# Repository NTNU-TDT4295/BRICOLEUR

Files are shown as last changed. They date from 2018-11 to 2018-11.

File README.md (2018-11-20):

# BRICOLEUR

This is the collision detection group's final submission for the course TDT4295 Computer Design Project 2018. This course aims to give students an introduction to the process of designing physical computer solutions, from start to finish. The project was completed on a budget of 10000 NOK, of which 5400 NOK were spent. 

## What is BRICOLEUR?
A bricoleur is someone who starts building something with no clear plan, adding bits here and there, cobbling together a whole while flying by the seat of their pants.

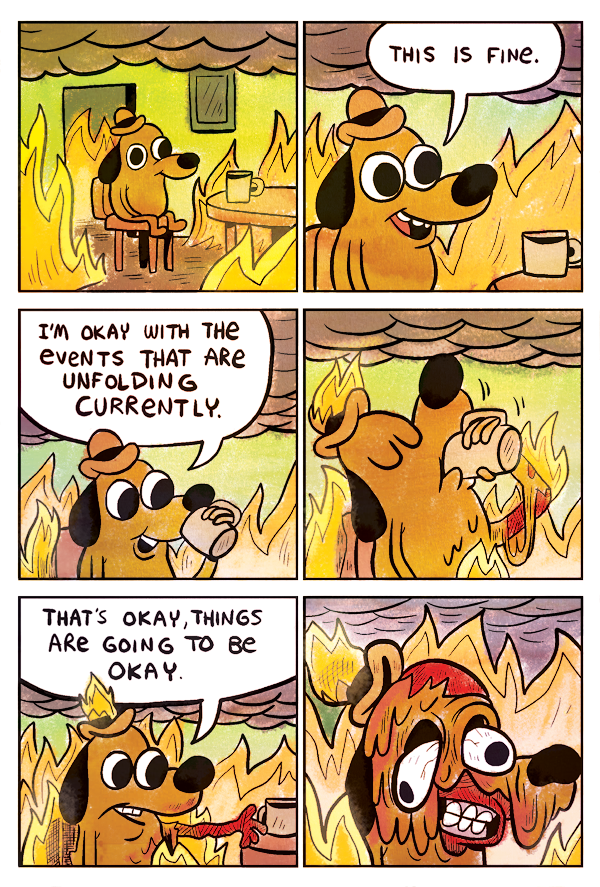
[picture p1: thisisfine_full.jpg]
We have everything under control Everything is fine


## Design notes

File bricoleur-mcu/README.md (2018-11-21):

# Ultrasonic

Reads ultrasonic sensors and processes the readings.
Uses the EFM32GG MCU and LV-MaxSonar-EZ0 rangefinders.

## Setup

Current setup uses an EFM32GG980 and two EZ0 rangefinders.

### Wiring (ultrasonic)

The EZ0 sends range data in inverted UART format.

| MCU | EZ0 |
|-----|---|
| 3V3 |  +5 |
| GND | GND |
| PA0 | TX\* |
| PA3 | RX\*\* |
| PA4 | RX\*\* |

\* The outputs from the sensors must be connected together with a "binary or".
This means that the signal from each sensor must go trough a diode before the signals are connected together and to the MCU. The signal must also have a pull-down resistor.

\*\* The RX pin on each sensor must be connected to its own pin on the MCU.

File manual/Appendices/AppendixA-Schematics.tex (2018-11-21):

\section{Appendix A: Schematics}
%TODO: Remove blank page
\label{AppendixA}
%\includepdf[pages=1,pagecommand={\subsection{Appendix A: Schematics} \thispagestyle{empty}}, fitpaper=true]{Images/Schematics-PleaseDoUseInReport.pdf} [width=155mm,height=220mm]
\includepdf[pages=1,fitpaper, width=216mm, height=297mm ]{Images/Schematics-PleaseDoUseInReport.pdf}
\includepdf[pages=2,fitpaper, width=216mm, height=297mm]{Images/Schematics-PleaseDoUseInReport.pdf}
\includepdf[pages=3,fitpaper, width=216mm, height=297mm]{Images/Schematics-PleaseDoUseInReport.pdf}
\includepdf[pages=4,fitpaper, width=216mm, height=297mm]{Images/Schematics-PleaseDoUseInReport.pdf}
\includepdf[pages=5,fitpaper, width=216mm, height=297mm]{Images/Schematics-PleaseDoUseInReport.pdf}

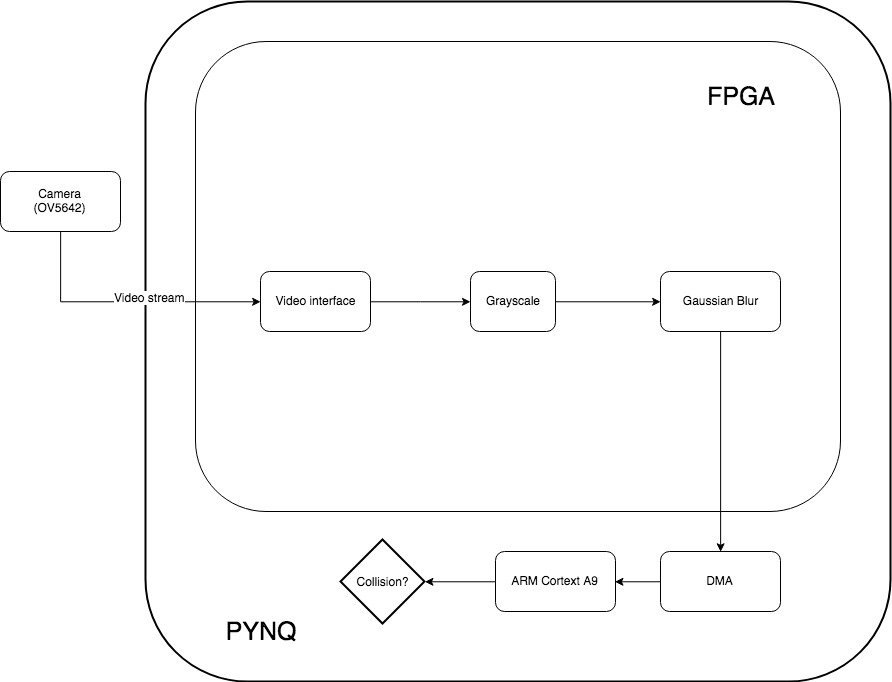
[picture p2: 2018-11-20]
manual/Images/Pipeline-Overview.jpg

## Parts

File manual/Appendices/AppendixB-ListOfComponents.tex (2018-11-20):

\section{Appendix B - Components}
The following is a list of all components used in the assembly of one copy of the BRICOLEUR system. 
\subsection{Pre-made components}
\begin{tabular}{c | r}
    Component & Quantity            \\ \hline
    CMOS OV5642 Camera Module  & 1  \\
    LV-MaxSonar-EZ0 MB1000 & 2      \\
    PYNQ-Z1 & 1                     \\
    Cardboard container & 1          \\
\end{tabular}

\subsection{PCB BOM}

\small
\begin{tabular}{@{} l|c|c|c|c|r @{}}
    Designation & Footprint & Stat & Distributor & Distributor ID & Qty \\ \hline
    U7 & QFP100 & EFM32GG980 & Mouser & 634-32GG980F1024-E & 1\\
    C18,C19 & 0402 & 27pF & Digikey & 478-11777-1-ND & 2 \\
    \parbox[t]{3cm}{C17,C3,C8,C9,\\C10,C11,C12} & 0402 & 100nF & Digikey & 1276-1004-1-ND & 7\\
    C1 & 0201 & 1$\mu$F & Digikey & 490-7229-1-ND & 1\\
    C4 & 0603 & 1$\mu$F & Digikey & 1276-6524-1-ND & 1\\
    C5, C13 & 0805 & 10$\mu$F & Digikey & 1276-6456-1-ND & 2\\
    C6, C7 & 0402 & 10nF & Digikey & 490-4762-1-ND & 2\\
    C14,C15,C16 & 0402 & 1nF & Digikey & 490-6348-1-ND & 3\\
    C2 & 0805 & 4.7$\mu$F & Digikey & 399-3134-1-ND & 1\\ \hline
    R14,R15,R17 & 0402 & 100k$\Omega$ & Digikey & MCS0402-100K-CFCT-ND & 3\\
    R1,R11,R12,R13 & 0402 & 100$\Omega$ & Digikey & RR05P100DCT-ND & 4\\
    R10,R9, R8 & 0402 & 3k$\Omega$ & Digikey & RR05P3.0KDCT-ND & 3\\
    R2, R3 & 0402 & 15$\Omega$ & Digikey & P15DDCT-ND & 2\\
    R4 & 0402 & 1$\Omega$ & Digikey & 311-1.00LRCT-ND & 1\\
    R5,R6,R7 & 0402 & 1M$\Omega$ & Digikey & 311-1.00MLRCT-ND & 3\\
    R16 & 0402 & 10k$\Omega$ & Digikey & RR05P10.0KDCT-ND & 1\\ \hline
    L1 & 0805 & 2200nH& Digikey & 732-1614-1-ND & 1 \\
    L2 & 0603 & 10$\mu$H & Digikey & 732-4484-1-ND & 1\\ \hline
    SW2,SW3,SW4,SW5 & 6x6mm & switch & Farnell & 2065105 & 4\\
    U9 & 3.1x3.0mm & 1pF 1MHz & Digikey & 1727-3578-1-ND & 1\\
    J1 & 8.4x6.4mm & USB\_Micro-B & Digikey & 609-4050-1-ND & 1\\
    U1,U3,U4,J3,J4 & 9.4x15.8mm & IDC 2x3 & Digikey & 609-2845-ND & 5\\  
    U5, U6, & 33.5x9.4mm & IDC 2x10 & Digikey & ED10524-ND & 2\\
    D1, D2, D3 & 0603 & LED & Digikey & 732-4981-1-ND & 3\\
    \parbox[t]{3cm}{D9,D18,D15,D16,\\D17,D6,D4,D19,\\D20,D11,D12,D13,\\D14,D7,D8,D10,\\D5} & SOT-23 & ESD & Farnell & 1081194RL & 17\\
    Header pins & -- & 2.54mm & $\Omega$Verksted & -- & 60\\
\end{tabular}
\normalsize

\subsection{Connectors}
\begin{tabular}{c|c|c|c|c|r}
    Designation & Stat & Distributor & Distributor ID & Qty \\ \hline
    IDC-Female small & 2x3pin & Digikey & 649-71600-306LF & 6\\
    IDC-Female med. & 2x10pin & Digikey & ED10503-ND & 3\\
    Flat cable & 6 lines & Digikey & 732-11799-ND & 1m\\
    Flat cable & 20 lines & Digikey & 732-11806-ND & 1m \\
    Diode & 100MHz & $\Omega$Verksted & -- & 2\\
\end{tabular}

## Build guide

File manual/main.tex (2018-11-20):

\documentclass{article}
\usepackage[utf8]{inputenc}
\usepackage{hyperref}
\usepackage{graphicx}
\usepackage{listings}
\usepackage[final]{pdfpages}
\usepackage{wrapfig}
\usepackage{listings}
\usepackage{color}
\usepackage{microtype}
\usepackage{xfrac}
\usepackage[normalem]{ulem}

\definecolor{dkgreen}{rgb}{0,0.6,0}
\definecolor{gray}{rgb}{0.5,0.5,0.5}
\definecolor{mauve}{rgb}{0.58,0,0.82}

\lstset{frame=tb,
  language=Bash,
  aboveskip=3mm,
  belowskip=3mm,
  showstringspaces=false,
  columns=flexible,
  basicstyle={\small\ttfamily},
  numbers=none,
  numberstyle=\tiny\color{gray},
  keywordstyle=\color{blue},
  commentstyle=\color{dkgreen},
  stringstyle=\color{mauve},
  breaklines=true,
  breakatwhitespace=true,
  tabsize=3
}

\begin{document}

\input{Text/TitlePage.tex}

\tableofcontents

\newpage

\input{Text/Acknowledgements.tex}

\newpage

\input{Text/Introduction.tex}

\newpage

\input{Text/Setup-complete.tex}

\newpage

\input{Text/Usage.tex}

\newpage

\input{Text/System-description.tex}

\newpage

\input{Appendices/AppendixA-Schematics.tex}

\newpage

\input{Appendices/AppendixB-ListOfComponents.tex}

\newpage

\input{Appendices/AppendixC-SoftwareAndToolChain.tex}

\newpage

\input{Appendices/AppendixE-PipelineFigures.tex}

\newpage

%For some stupid reason Overleaf does not support mid-line commenting, and colorlinks does nothing, except give a warning
\hypersetup{%colorlinks=true, 
linkcolor = myblue}

\bibliographystyle{plain}
\bibliography{refs}

\end{document}

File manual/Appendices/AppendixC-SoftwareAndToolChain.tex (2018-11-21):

\section{Appendix C - Software and Tools}

\begin{description} 
    \label{vSoftware}
    \item [Vivado 2018.2] Used for importing Chisel 3 components in the form of Verilog files, wiring them up and connecting to other parts of the PYNQ board, like the DMA controller.
    \item [Simplicity Studio 4] Silicon Labs' standard IDE for EFM chips.
    \item [KiCAD 5.0.1] Primary PCB design tool. 
    \item [Macaos] PCB verification and ordering through intermediate supplier. 
    \item [efm32-base] An EFM32 base project that allows development on the command line. \url{https://github.com/ryankurte/efm32-base/}
    \item [Chisel] 3.1.3. Library used to write hardware components that are imported into Vivado.
    \item [SBT] 1.1.1. Used to compile and test Chisel project.
    \item [Scala] 2.11.12. Programming language that Chisel components are written in.
    \item [Xilinx PYNQ] PYNQ-Z1 v2.3
    \item [gcc] 7.2.1
    \item [arm-none-eabi toolchain] 7.2\_2017q4
    \item [GNU netcat] For piping data between laptop and PYNQ over TCP
    \item [ffmpeg] To decode video to raw grayscale and to play the debug video output
\end{description}

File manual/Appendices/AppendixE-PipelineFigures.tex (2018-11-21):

\section{Appendix E - Pipeline figures}

%\subsection{High-level overview}

\subsection{Gaussian Blur}

\begin{figure}[!hbpt]
    \centering
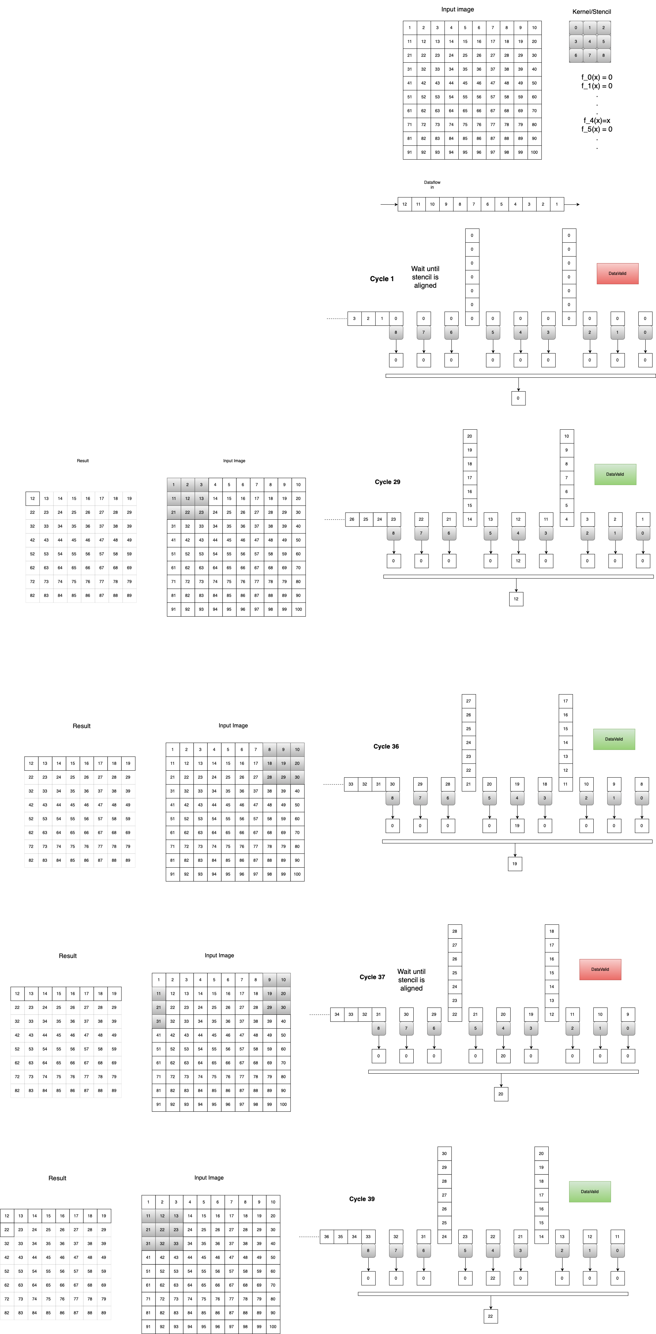
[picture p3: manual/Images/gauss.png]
    
    \caption{Illustration of the logical functionality of the  Gaussian Blur component.}
    \label{fig:gauss}
\end{figure}

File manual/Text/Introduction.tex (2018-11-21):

\section{Introduction}
% Vague bullshit
This is the collision detection group's final submission for the course TDT4295 Computer Design Project 2018. This course aims to give students an introduction to the process of designing physical computer solutions, from start to finish. The project was completed on a budget of 10000 NOK, of which 5400 NOK were spent. 

\subsection{What is BRICOLEUR?}

A bricoleur is someone who starts building something with no clear plan, adding bits here and there, cobbling together a whole while flying by the seat of their pants. 

The overarching goal of the project was to develop a stationary system which is able to detect moving objects, estimate their velocity and direction of motion, and finally predict a potential collision. In order to create concrete requirements for the minimum viable product, this was further reduced to the system being able to "predict collision with a single high-contrast object of reasonable size, moving in a straight line, and going no faster than 20 \sfrac{m}{s}".

\subsubsection{Additional requirements}
In addition to solving the problem described above, the project was to follow these constraints: 
\begin{itemize}
    \item The FPGA on the PYNQ must be used to perform meaningful acceleration of calculations. 
    \item The system must make use of a custom printed circuit board, which houses a micro control unit that is actively involved in the problem's solution. 
\end{itemize}

\subsection{Basic outline of solution}
The solution makes use of one camera and multiple ultrasonic sensors to detect incoming objects. The main code runs in Python on the PYNQ CPU, and is receiving images from the accelerator implemented on the FPGA. When the CPU has detected an incoming object it will send a signal to the microprocessor on the PCB that something is incoming. The ultrasonic sensors report directly to the microprocessor. The microprocessor will then output a byte value on UART, which indicates how sure it is that the object will collide both from the data from the CPU and from the ultrasonic sensors. 

\begin{figure}
    \centering
    
    \caption{The contents of the final deliverable}
    \label{fig:finito}
\end{figure}

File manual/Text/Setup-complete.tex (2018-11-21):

\section{Setup - Step by step}
Building the project from nothing can be a quite involved process. Reserve plenty of time and prepare a cup of tea. 

\subsection{Getting started}
To get started with the PYNQ one must first set it up properly and hook it up to a computer. Start by following this guide:\\
\url{https://pynq.readthedocs.io/en/latest/getting_started.html}

\subsection{Installing dependencies}
If the latest PYNQ image (\ref{vSoftware}) is used, all of the dependencies used in the project come pre-installed.

However, if for some reason OpenCV for Python or Numpy are unavailable, it is highly recommended that you hook the PYNQ up to an Internet connection in order to download the dependencies easily.

\subsection{Development environment}
On your development computer you will need to install Vivado 2018.2 to continue development. This can be downloaded from here: \url{https://www.xilinx.com/support/download.html}. And good luck.

\subsection{Scala and Chisel 3 Modules}\label{ScalaChiselSub}
The accelerator modules are written using Chisel 3. You will first need to set up Chisel 3 and Scala. Follow the guide in the Chisel repository: \url{https://github.com/freechipsproject/chisel3}.

To be able to add your Chisel module into the Vivado project you need to compile the Chisel code into Verilog. The Verilog files will be imported into the Vivado project when it is created.

\subsection{Loading project into Vivado}
In the BRICOLEUR GitHub repository you will find a \texttt{pipeline.tcl} file that you will need to import our modules into the Vivado project. The rough outline below will demonstrate how this is set up:

\begin{itemize}
    \item Start Vivado 2018.2
    \item Create a new RTL project
    \item During the wizard it will ask for a set of source files, which are the Verilog files compiled in \ref{ScalaChiselSub}.
    \item After creating the project, go into the Tools menu and click \texttt{Run TCL Script} and locate the aforementioned \texttt{pipeline.tcl} file.
    \item Make sure to set the correct project constraints compatible with the PYNQ.
\end{itemize}

\subsection{Exporting Vivado project}
When you have added your new module to the project and connected your module in the block design you can generate the bitstream. Press \texttt{Generate bitstream} and \underline{\underline{wait}}.

When the bitstream is created you are ready to export it for execution on the PYNQ. Click on \texttt{File} and then \texttt{Export bitstream} and save it somewhere. You will now have to transfer this file onto the PYNQ to be utilized within the Python environment.

\subsection{Run on the PYNQ}
Run the python script on the PYNQ system and make sure to import your newly updated bitstream.

To upload to the PYNQ, run these commands:
\lstset{basicstyle=\small}
\begin{lstlisting}[language=bash]
scp <pathToBitstream>/design.bit xilinx@192.168.2.99:/home/xilinx/
scp <pathToTclScript>/design.tcl xilinx@192.168.2.99:/home/xilinx/
\end{lstlisting}

\subsection{Preparing the BRICOLEUR PCB}

\subsubsection{Programming the MCU}
You will need: 

\begin{itemize}
    \item 1 USB-UART device + USB cable
    \item Female-female jumper cables
    \item A way to supply power to the board (USB-micro cable/PYNQ board)
\end{itemize}

The EFM32GG980 can be programmed using the bootloader which comes pre-installed on the chip. Compile the MCU code to produce the desired \texttt{.bin} file. Depending on your method of development, make sure that the loader sets a base offset of 0x4000, to respect the bootloader's space. Also reduce the available flash memory accordingly. Then prepare the PCB for flashing. 
\begin{enumerate}
    \item Connect the USB-UART device to your computer, make sure it works. 
    \item Connect the UART device to the UART\_BOOT port, between the MCU and the logo, on the PCB. Pin 6 should be connected to RX, and pin 4 to TX.
    \item Using a jumper, connect pin 9 on the PCB debug connector (top left corner) to pin 1 (VMCU). This enables launch to bootloader instead of an existing program.
    \item Connect a power source to the PCB. 
    \item Launch your serial communication program of choice, such as Screen, MiniCom or Putty. 
    \item Push the reset button, located closest to the MCU. 
    \item Quickly send the character 'U' to initialize bootloader communication. 
    \item Then send 'u' to perform a non-destructive upload. 
    \item Using Xmodem-CRC, transfer the binary. In 'screen' this would be done by pressing Ctrl-a, followed by ':', and the command: 
    \lstset{basicstyle=\small}
    \begin{lstlisting}[language=bash]
        exec !! sx bricoleur.bin
    \end{lstlisting}
    \item Verify that the program runs as expected by sending 'b'. 
\end{enumerate}

\subsection{Putting everything together}

\begin{wrapfigure}{R}{0.4\textwidth}
    \centering
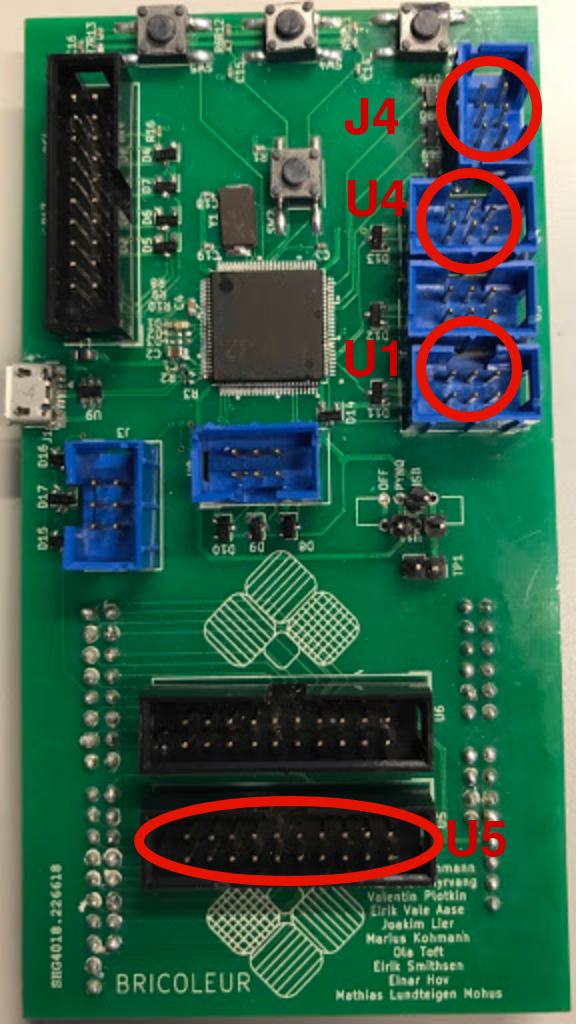
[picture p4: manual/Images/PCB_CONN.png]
    
    \caption{Connections for basic functionality}
    \label{fig:pcb_connections}
\end{wrapfigure}

Assemble the boards as shown on the image. The BRICOLEUR system can be configured in multiple ways. However, in order to reproduce the demo-build, connect it as follows:

\begin{enumerate}
    \item Connect U1 to the left ultrasonic sensor, and U4 to the right one. 
    \item Connect the top right IDC (J4) to an external unit. 
    \item \sout{Connect the OV5642 camera to U5.} Connect the ethernet cable to the PYNQ instead. 
    \item Connect a jumper or physical switch to the desired power source pin, in this case the PYNQ, and the VMCU pin (bottom left on  switch area).
    \item Put the PCB on top of the PYNQ by joining the matching headers.
\end{enumerate}

%Clearpage is here to prevent wrapfigure fuckup, since the PCB figure wraps on the section under, preventing the ultrasound placement figure to wrap this section (for some reason, i guess Overleaf doesn't like wrapping on the same section of text)

\subsubsection{Sensor placement}

\begin{wrapfigure}{R}{0.31\textwidth}
    \centering
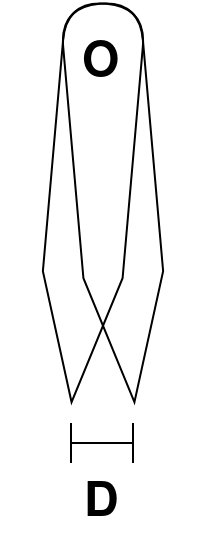
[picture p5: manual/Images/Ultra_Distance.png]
    
    \caption{Things to consider when placing sensors}
    \label{fig:ultra_dist}
\end{wrapfigure}

The positioning of the ultrasonic sensors is based on two main variables: Area of overlap and distance between the sensors. Both should be maximised to achieve the best results.

A larger area of overlap means there is a larger area where both sensors will detect the object, and therefore be able to do meaningful calculations. A larger distance \texttt{D} between the sensors gives a larger difference in the distance from each sensor to object \texttt{O}. This in turn makes it easier to calculate an accurate X-coordinate of the object, but it also lowers the area of overlap.

The demo build chose a distance of 30.5 cm.

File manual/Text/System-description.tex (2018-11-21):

\section{System description}

\subsection{The sensors}
During the project's early stages, an evaluation of potential sensors was performed. It was then concluded that a combination of up to two cameras in addition to a set of ultrasonic sensors would be the most reliable tools to complete the task. The exact number of each sensor was determined at a later time, when the group had a clearer concept of the FPGA's strengths and limitations. In the end it was settled that the final system should use a single camera and two ultrasonic sensors. 

\subsubsection{CMOS OV5642 Camera Module }
The camera sensor is the system's primary sensor. The purpose of the camera is to deliver images in 320x240 resolution to the accelerator so that it can pre-process the images before the CPU calculates on them. For this task the OV5642 was selected because of accessible hardware interface, comparatively low cost, and support for high frame rates. After starting to work with the camera, it became clear that the documentation for the camera module which was accessible was insufficient for configuring it to our purpose. Configuring registers over I$^{2}$C and reading raw sensor data over the DVP bus works, as does cropping the output. However, attempts to change color format or scaling the output image failed. In the end, the camera module was abandoned, and video files and laptop cameras were used as a workaround.

\subsubsection{Maxbotix Ultrasonic Rangefinder}
We use the ultrasonic sensors Maxbotix Ultrasonic Rangefinders, model LV-MaxSonar-EZ0. Their purposes is to determine the direction of a moving object and send the result to the microprocessor on the PCB. Although their data are intended to supplement information derived from the camera, the ultrasonic sensors may also function as a backup, should the camera fail. 

\subsection{Accelerator}
The custom accelerator is designed to process images from the camera and give the images to the CPU to ease the work for the CPU. The reason for this accelerator being needed is that the algorithm which is used for detection of moving objects needs the images to be Gaussian blurred before it is able to determine if there is an moving object. Because this process is a time consuming task for the CPU it needs to be blazingly fast, so that the CPU can process frames on a high frame rate. The overview of the accelerator in the final design is shown in Figure \ref{fig:fpga1}. The intended design is shown in Figure \ref{fig:fpga2}.

\begin{figure}
    \centering
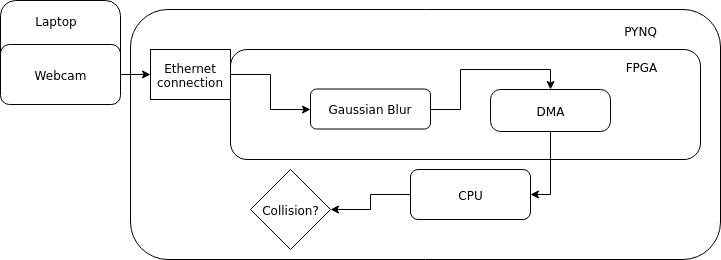
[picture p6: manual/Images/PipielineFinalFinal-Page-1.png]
    
    \caption{Final FPGA design overview}
    \label{fig:fpga1}
\end{figure}

\begin{figure}
    \centering
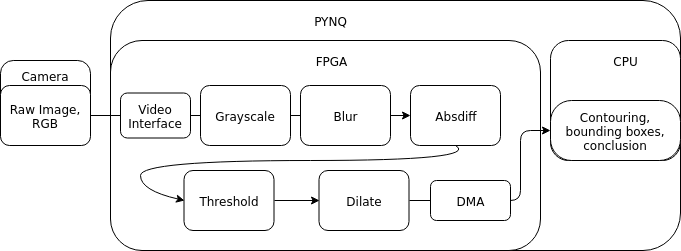
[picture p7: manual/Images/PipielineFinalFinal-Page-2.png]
    
    \caption{Intended accelerator overview}
    \label{fig:fpga2}
\end{figure}

The Gaussian Blur accelerator is modelled after \cite{cong2014optimal} and looks like figure [\ref{fig:fpga1}].

\subsection{Accelerator pipeline}
The accelerator's pipeline follows a sequential pattern [\ref{fig:Real_Pipe}], meaning the pixels are inputted from left to right, top to bottom. The reason for this is avoiding unnecessary complexity, since the intended camera model outputs the pixel-values in this fashion. Another reason is that this method is able to get the throughput needed, it has the least amount of latency, and uses the least amount of resources.

The alternative method to a sequential pipeline would be a way to partly load pixel-values vertically, instead of horizontally. Figure \ref{fig:Alt_Pipe} shows this pattern. This, however, makes no sense without hardware support, which the camera does not have. If the camera would be able to output pixels in chunks equal to the Gaussian Blur kernel, it would make sense to use this, to lower the latency from the Gaussian Blur filter.
\begin{figure}
    \centering
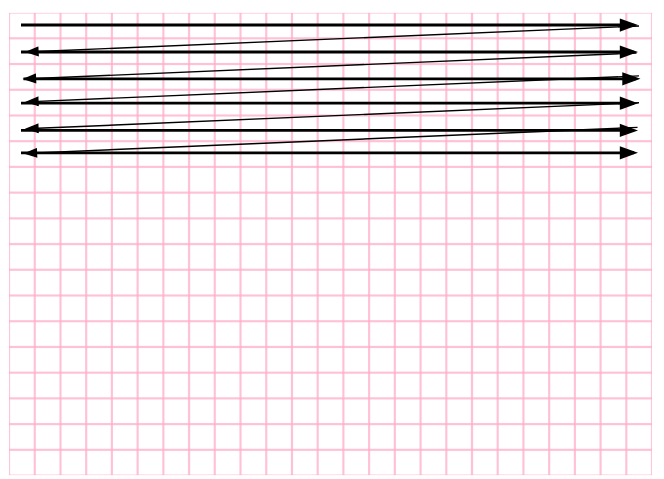
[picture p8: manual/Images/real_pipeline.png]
    
    \caption{Real pipeline}
    \label{fig:Real_Pipe}
\end{figure}

\begin{figure}
    \centering
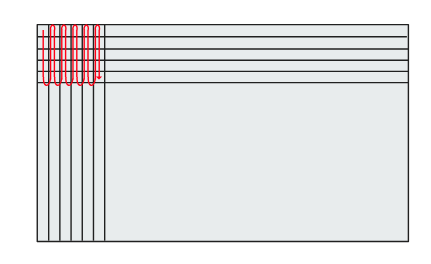
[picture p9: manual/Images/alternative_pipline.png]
    
    \caption{Alternative pipeline}
    \label{fig:Alt_Pipe}
\end{figure}

\subsubsection{Video interface}
The video interface receives signals from the camera module and produces a stream of pixels. The communication between the camera and the video interface is clocked by the pixel clock from the camera. A vertical synchronization 
signal signifies the end of a frame and the start of a new frame. The href signal signifies that the 8-bit data bus is currently holding valid pixel data. Using these signals and the data bus, the video interface reads image frames from the camera module.

As the camera module was abandoned due to difficulties configuring it, the video interface is not used in the final product.

\subsubsection{Grayscale}
The grayscale component is the first step of the pipeline after pixel values are sent from the data source. It grayscales an image with the following equation:

\begin{equation}
    o = r \times 0.3 + g \times 0.59 + b \times 0.11
\end{equation}

where $r$, $g$ and $b$ are the respective RGB channel values and $o$ is the output, namely the resulting grayscaled value.

It incrementally produces this sum, outputting the grayscaled value when the blue value arrives, then resets and starts over again with the next pixel. This ensures that the grayscale only has 3 clock-cycles of latency, and a throughput of one third of the input, meaning no data is lost.

This module is not used in the final product, as converting the image to grayscale before piping the data to the PYNQ saved two thirds of the bandwidth used over the network interface.

\subsubsection{Gaussian blur}
The Gaussian blur part of the accelerator takes grayscaled values as input and blurs them using a computational kernel. Because Gaussian blur needs to calculate the resulting pixel value from pixels directly adjacent to it, it is necessary to store the pixels for later use. This is done by creating a series of queues, as outlined in Figure \ref{fig:gauss}, and outputting the correct values through the filter kernel.

\subsubsection{Absdiff}
Absdiff is utilized to find the absolute difference in value between the same pixel from consecutive images. The module takes grayscale-values as input, and outputs the absolute difference.

It does this by inserting all values of the current frame into a queue. The next input value will then be the first value of the next frame, and the absolute difference between them is output by the module.

Due to unresolved bugs, this module was not incorporated in the final design.

\subsubsection{Threshold}
Threshold is used to filter out any noise from the Absdiff by creating a binary image. Small values from Absdiff are more likely to come from random noise than from an actual object moving in the picture.

Threshold is implemented by checking the input values, and output a value of 255 if it exceeds the threshold, and a value of 0 if it does not exceed it.

This module was also not used in the final design, as the module directly before it was excluded from the design.

\subsubsection{Dilate}
Dilation is an image filtering operation where in a given area on the image the maximum value is chosen and replaces the center value in the chosen area. This module was implemented, tested and was proven functional, however including it in the final design was deemed impractical, due to its position in the pipeline. 
\subsubsection{DMA}
When the Gaussian blur component is finished doing its work, the pixel values are passed in to the DMA for fast transfer into DDR memory and direct access by the CPU.
The DMA module is an IP block provided by the Vivado IP library.

\subsection{The PYNQ CPU}
The Cortex-A9 CPU is used on the PYNQ to further process the images from the FPGA. The CPU runs Python code that reads images from memory and calculates whether there is an incoming object or not. The images which are read from memory have been pre-processed by the custom accelerator for the CPU to work with. The images are already grayscaled and Gaussian blurred to make it easier to detect movement. The algorithm for the detection of incoming objects works as follows:

\begin{enumerate}
    \item Two pre-processed images from the camera are compared to each other to find out where something has been moving
    \item The size of the area that has been changed is calculated and stored. 
    \item When a new image is received in the next frame, the processor can determine if the new area that is changed is bigger or smaller than the previously stored value. If the area is bigger something is incoming.
\end{enumerate}

OpenCV is utilized to perform these calculations. When an incoming object is detected, a signal is sent to the MCU through a 3-bit data bus to the PCB. These lines transmit a value ranging from 0 to 7 indicating the estimated probability of a collision.

\subsection{The Microprocessor}
% Stats
\subsubsection{Specification} % Title pending
The EFM32GG980F1024-QFP100 was selected to be the PCB's MCU because of its flexibility and feature-richness. This made it possible to progress quickly on other parts of the design, before the exact details of its operation were decided upon. The chips most important qualities for this project were:
%TODO: Reasons why these are important? 
\begin{itemize}
    \item Comparatively high processing power
    \item Support for a number of protocols such as UART, USART and USB 
    \item Familiarity to group members
    \item QFP100 14x14mm package (simpler to solder than alternatives) %Non-solder-hell
\end{itemize}

\subsubsection{Device Communication}
%See \autoref{fig:PCB_COMM}.
\begin{figure}[h!]
    \centering
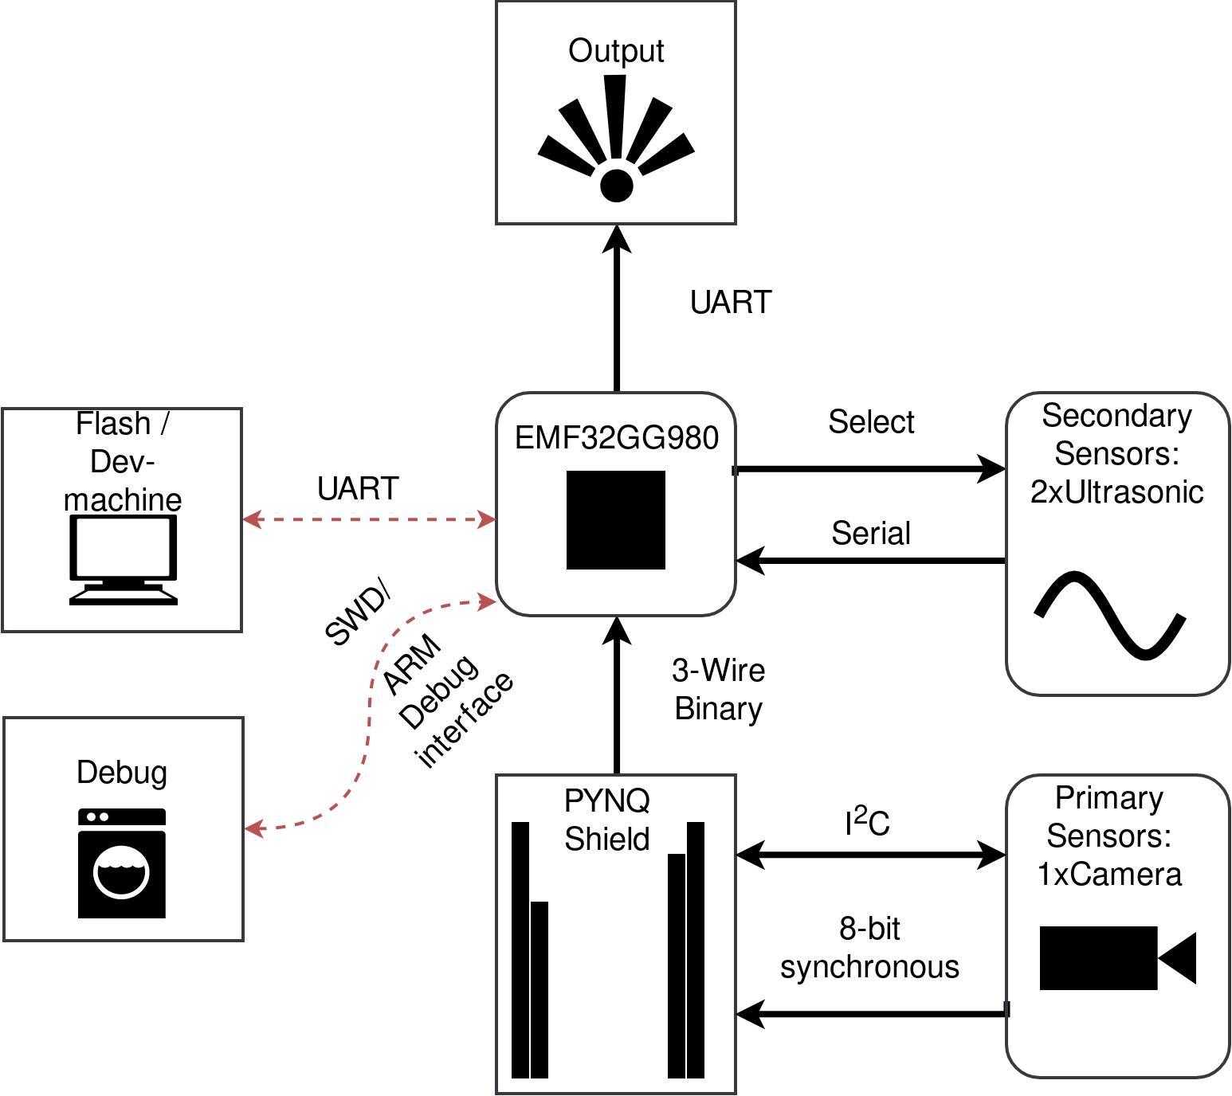
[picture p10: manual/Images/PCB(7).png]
    
    \caption{Communication on the BRICOLEUR PCB}
    \label{fig:PCB_COMM}
\end{figure}

\subsubsection{Ultrasonic analysis}

Each of the ultrasonic sensors will detect a different distance to an object. This difference can be used to calculate the position of the object relative to the sensors with a technique known as trilateration:

\begin{itemize}
    \item Let each sensor be the center of a circle, and let the distance to the object be the radius of the circle. Then the position of the object may be found by calculating the intersection of the circles. This is illustrated in Figure \ref{fig:ultrasonic_trilateration}.
    \item Please note that for two circles there will be two solutions, but one of these solutions will be behind the sensors, and can therefore be ignored.
    \item Also note that two circles will only give a 2D position, but this is sufficient to meet the assumption of an object moving along the ground. If the system should be expanded to handle objects thrown through the air, there would be a need for three sensors in order to find the 3D intersection point of three spheres. This would have four solutions, but only one of the solutions would be both in front of the sensors and above the ground.
    \item Once the position of the object at a given time is found, it is possible to measure the change in position over time. These positions can then be used to estimate velocity and interpolate a line, which in turn can used to estimate the future position of the object. This is illustrated in Figure \ref{fig:ultrasonic_motion}.
    \item By looking at where the object will intersect the x-axis (the system is at $y = 0$), one can conclude whether the object will collide heads-on, hit the edge of our system, or misses it completely. This means that even if an object is moving toward the sensors, it is possible to detect that it will actually miss the system.
\end{itemize}

\begin{figure}[h!]
    \centering
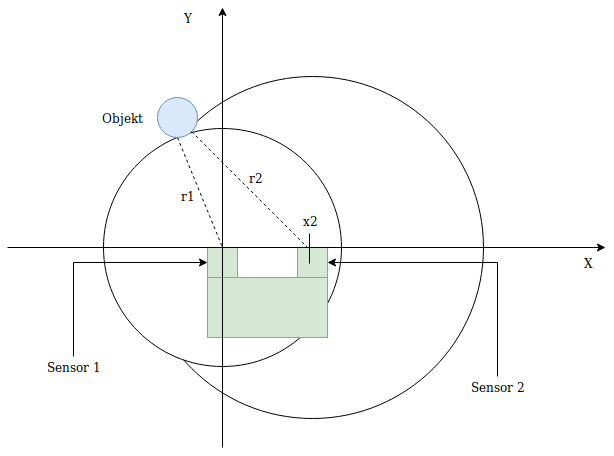
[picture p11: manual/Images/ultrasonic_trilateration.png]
    
    \caption{Ultrasonic: The difference in distance is used to find the position of the object}
    \label{fig:ultrasonic_trilateration}
\end{figure}

\begin{figure}[h!]
    \centering
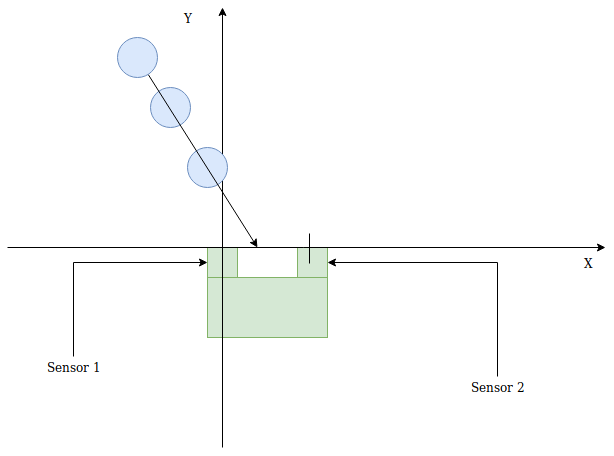
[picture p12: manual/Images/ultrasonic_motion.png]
    
    \caption{Ultrasonic: The different positions over time are used to estimate the future position of the object}
    \label{fig:ultrasonic_motion}
\end{figure}
\clearpage
% How do we determine what to output 
\subsubsection{Combining the conclusions from the camera and ultrasonic sensors}

Both the camera system and the ultrasonic system output a probability of collision. In order to combine these conclusions, we have to take into account that the delay of the systems might be different. If we simply take a (weighted) average, we could risk that one of the systems output a high probability while the other outputs a low probability, and shortly after the opposite happens. This would then only lead to a medium value, even if both the systems report a high probability of collision, just with a delay between them.

Because of this, we simply take the maximum value of the two conclusions, which ensures that the final conclusion is not lower than it should be.

\subsection{The PCB}

\begin{wrapfigure}{R}{0.4\textwidth}
    \centering
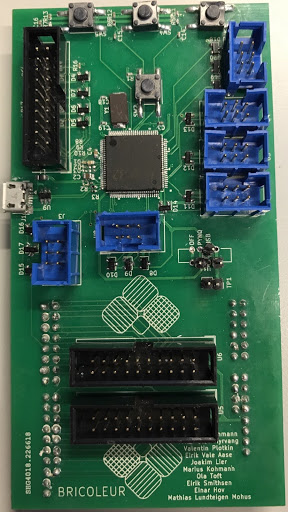
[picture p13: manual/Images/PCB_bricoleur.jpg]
    
    \caption{Assembled PCB}
    \label{fig:pcb}
\end{wrapfigure}

In order to cleanly connect the project's various components, a custom PCB was designed. The design behind the BRICOLEUR PCB was inspired by SiliconLabs' STK3700 board, in part because of the similar MCUs. Schematics and a complete list of components can be found in appendix A: Schematics and B: Components.

\subsubsection{Features}
\begin{itemize}
    \item Three switchable power sources: USB, PYNQ and external.
    \item J-Link compatible debug header
    \item Two camera headers 
    \item Three ultrasonic sensor connectors
    \item Header for UART-based bootloader communication
    \item Two UART/USART compatible input/output headers
    \item Arduino-compatible main header
    \item ESD protection on all inputs
    \item Debug LEDs and buttons
\end{itemize}

\subsubsection{Design}
The PCB was designed to be in accordance with Silicon Labs' application notes. The following documents were found to be of particular relevance:
\begin{itemize}
    \item AN0002 - Hardware Design considerations
    \item AN0003 - UART Bootloader
    \item AN0042 - USB/UART Bootloader
    \item AN0046 - USB Hardware Design Guide
\end{itemize}
% TODO: Noen jeg har glemt?

\subsubsection{Power supply}
The BRICOLEUR PCB is designed to operate at 3.3V. Other voltages are not officially supported, and all parts connected to the board are expected to operate at this voltage level. Power may be supplied to the board and its components in three ways: 

%Fuckings fuckleaf dont like enumeration with wrappings, pathetic
\begin{enumerate}
    \item USB: A microUSB cable can be connected directly to the board from a power supplying USB device. The MCU's internal voltage regulator converts the USB standard's 5V to 3.3V, which is then output on all power lines. Note that the PCB will not be able to power other devices through USB, even if it is provided power from another source. 
    \item PYNQ: The PYNQ Z1 Arduino Uno-style header contains a power pin which can output 3.3V directly to the PCB. This is expected to be the main mode of operation for the system.
    \item Header: A dedicated power pin has been exposed. It is intended primarily for debugging and as a backup. This point of entry has no safeguards: Be careful to ONLY apply 3.3V. 
\end{enumerate}

\subsubsection{PCB bricolage}
Shortly after placing the PCB order it was discovered that the way in which the ultrasonic sensors were connected would require some additional hardware, namely diodes. The reason for this was the pin-saving way in which the sensor outputs were wired. Since each ultrasonic sensor would be polled in order, out of fear for interference, it was thought that they could safely share a single MCU input pin. However, this opened up for the possibility that the high signal from one sensor could be sent to another sensor whose pin was currently driven low, causing a short circuit. Diodes solve this issue by  limiting the current direction. Because the board had no additional space for diodes, the cables were instead selected to be their mounting point.

Additionally, it turns out that the footprint intended for the power switch was poorly dimensioned. This has been amended by replacing the switch with a set of header pins and an externally wired power switch. A jumper between the correct pins can perform the switch's duty as well. 

\begin{figure}[h!]
    \centering
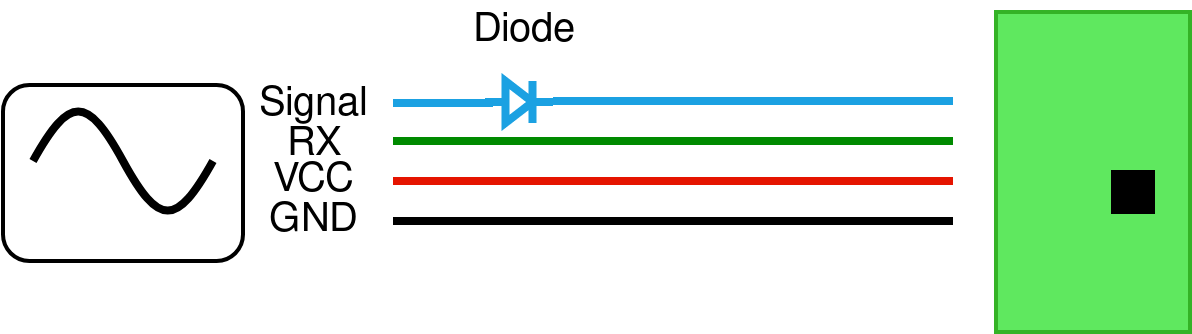
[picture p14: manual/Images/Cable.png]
    
    \caption{The cables connecting the ultrasonic sensors to the PCB}
    \label{fig:cable}
\end{figure}

\clearpage

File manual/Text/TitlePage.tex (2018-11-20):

\begin{titlepage}

\newcommand{\HRule}{\rule{\linewidth}{0.5mm}} % Defines a new command for the horizontal lines, change thickness here

\center % Center everything on the page
 
%----------------------------------------------------------------------------------------
%	LOGO SECTION
%----------------------------------------------------------------------------------------

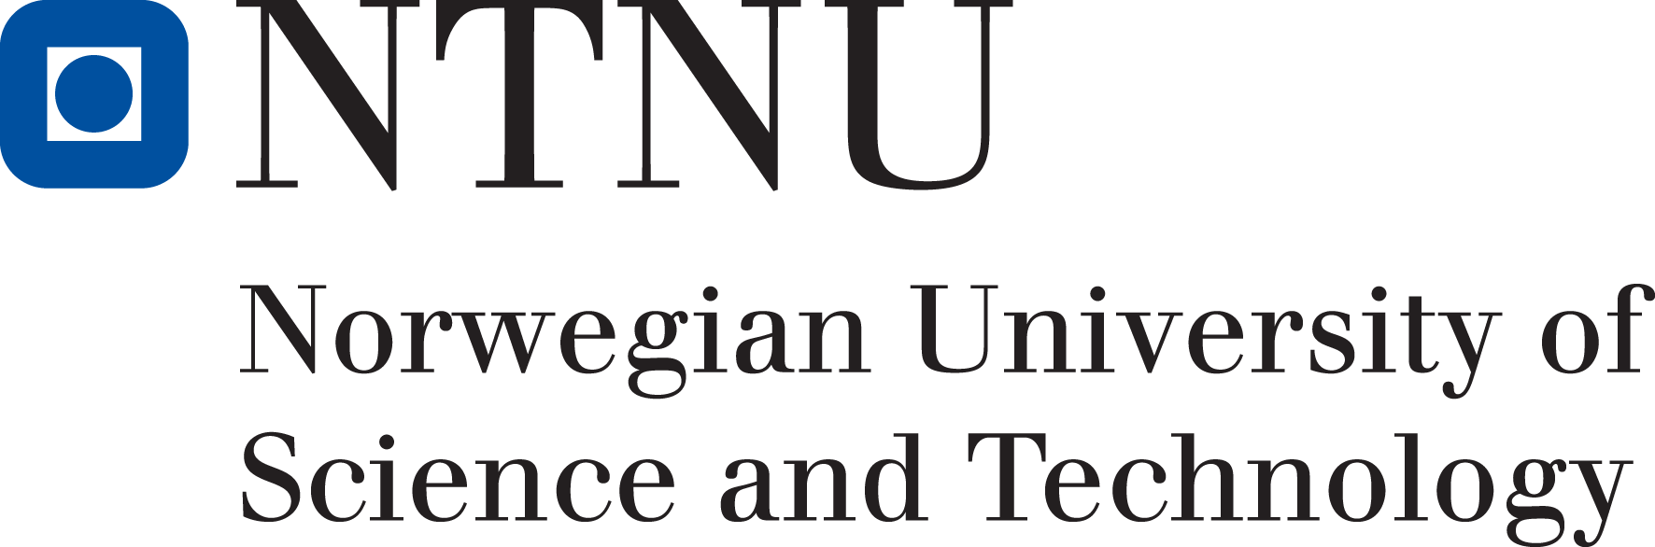
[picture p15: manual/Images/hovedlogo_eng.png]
\\[1cm] % Include a department/university logo - this will require the graphicx package
 
%----------------------------------------------------------------------------------------

%----------------------------------------------------------------------------------------
%	HEADING SECTIONS
%----------------------------------------------------------------------------------------

%\textsc{\LARGE NTNU}\\[1.5cm] % Name of your university/college
\textsc{\Large TDT4295 - Computer Design Project}\\[0.5cm] % Major heading such as course name

%----------------------------------------------------------------------------------------
%	TITLE SECTION
%----------------------------------------------------------------------------------------

\HRule \\[0.4cm]
{ \huge \bfseries User Manual}\\[0.4cm] % Title of your document
\HRule \\[0.5cm]

%----------------------------------------------------------------------------------------
%	AUTHOR SECTION
%----------------------------------------------------------------------------------------

\begin{minipage}{0.4\textwidth}
\begin{center} \large
\emph{Collision Detection Group:}\\
\small
Eirik Vale Aase\\
Richard Bachmann\\
Einar Hov\\
Marius Kohmann\\ 
Joakim Lier\\
Mathias Lundteigen Mohus\\
Fritz-Olav Myrvang\\
Valentin Plotkin\\
Eirik Smithsen\\
Ola Toft
\normalsize
\end{center}
\end{minipage}

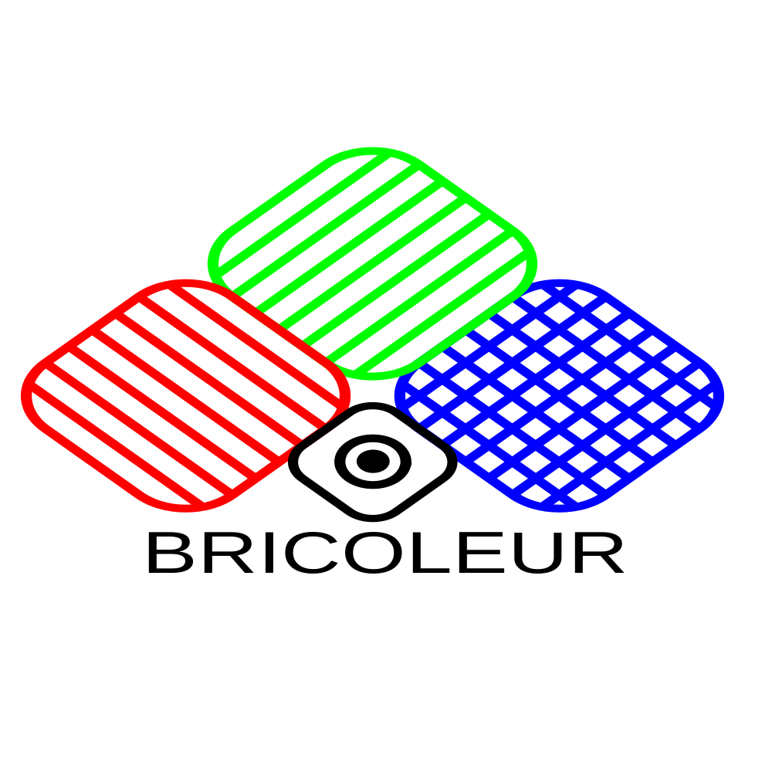
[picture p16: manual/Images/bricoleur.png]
\\

%----------------------------------------------------------------------------------------
%	DATE SECTION
%----------------------------------------------------------------------------------------
\vskip 1cm
\today\\
\url{https://github.com/NTNU-TDT4295/BRICOLEUR/}
\vfill

\vfill % Fill the rest of the page with whitespace

\end{titlepage}

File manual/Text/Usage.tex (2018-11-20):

\section{Usage}
%Throw some shit at the PYNQ in front of its cameras and ultrasonic sensors.
Once the system is assembled, place it on a flat surface and connect the power supply for the PYNQ. Optionally connect a visualization unit. Turn on the power supply for the PCB. The MCU will then calibrate the ultrasonic sensors, and begin normal operation.

\subsection{Video force feeding}
In the event that the project's camera should fail, it is possible to send externally recorded video to the PYNQ. For instance, a pre-recorded video, or even the feed from a laptop webcam, may be used for this purpose. The Python script performing the tracking algorithm reads raw frames from stdin, so the data can be piped in from f.ex. a file or netcat. The following shell commands were used to successfully pipe a laptop's webcam through the algorithm on the PYNQ.

\lstset{basicstyle=\footnotesize}
\begin{lstlisting}[language=bash]
# On the PYNQ
sudo sh -c 'nc -l -p 420 | ./video-mp.py'
# On the laptop
ffmpeg -i /dev/video0 -f rawvideo -s 320x240 -pix_fmt gray8 - \
    | nc xilinx@192.168.2.99 420
\end{lstlisting}

\subsection{Observations}
% Hva så vi under tests?

The ultrasonic sensors read distances correctly, however the employed algorithm proved to be somewhat unstable. The camera worked better, but still struggled with larger distances to the target object. Sadly, the delay between the ultrasonic and camera readings made it difficult to combine their results without sacrificing latency. 

\subsection{Output}
% Description of what final output is
Bricoleur output can be read from the AUX-port. By default it will be transmitted through UART with a baudrate of 115200. The output is a byte value, ranging from 0 to 255. Here 0 indicates no sensed danger of collision, and 255 indicates certain collision. This output is weighted combination of the PYNQ's output and the conclusion of the ultrasonic analysis. 

The PYNQ will also output video frames---annotated with bounding boxes of tracked objects---to a file. The file can either be analyzed afterwards, or used for real-time monitoring of the system. During testing, we have played back the annotated video real-time on a connected laptop by using the following shell commands before starting the Python script.

\lstset{basicstyle=\footnotesize}
\begin{lstlisting}[language=bash]
# On the laptop
nc -l -p 4200 | ffplay -f rawvideo -pixel_format gray8 \
    -framerate 144 -video_size 318x238 -
# On the PYNQ
mkfifo debugframes.raw
nc 192.168.2.1 4200 < debugframes.raw
\end{lstlisting}

\subsubsection{Visualisation suggestion}
% Description of servo/output unit
For the demonstration an external system was used to turn the output byte value into something more tangible. This device consisted of an Arduino Uno, which read the transmitted serial data, and a servo, which pointed a needle to indicate level of panic. 
% Include image

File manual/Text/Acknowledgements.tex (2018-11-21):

\section{Acknowledgements}
\textbf{Odd Rune Lykkebø} for teaching us the ways of hardware.\\
\textbf{Omega Verksted} for providing the optimal work environment and lending their expertise. 

%Thanks to \texttt{Github} for storing our work in the \texttt{cloud}.

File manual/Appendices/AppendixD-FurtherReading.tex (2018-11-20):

\section{Appendix D - Further Reading}
TODO: Replace with references?

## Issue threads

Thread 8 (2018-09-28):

Analyze algorithm and pipeline

eirikvaa, 2018-09-28:
We have to analyze the algorithm and pipeline to figure out:

- How long does the execution take?
- How much data passes between each phase, and at what rate?
- Single or multi-threaded?

(Update this issue with new points as they come up)

eirikvaa, 2018-09-30:
I guess in this we also must decide the maximum speed at which the object can move towards the camera.

Closed 2018-10-12.

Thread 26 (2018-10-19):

Handle mixed integer and non-integer inputs to the filters.

JoakimOL, 2018-10-19:
We need to preserve the amount of bits in the output, so we can reinterpret it as a fixed point number later. When using the dilate filter, using only integers, some bits seems to be stripped (as scala/chisel deems the uneccessary?). This is causing problems as they need to be handled a different way than the fixed point numbers with both integer and fractional parts.

Closed 2018-11-07.

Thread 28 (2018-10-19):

Calibrate ultrasonic sensor to know where the wall is

olatoft, 2018-10-19:
On startup, get the position of the wall, i.e. the position of the closest, non-moving object before other moving objects arrive.

That way, we can figure out there is no moving object visible and we are looking at the wall, or if we are simply looking at a slow-moving object.

Closed 2018-11-21.

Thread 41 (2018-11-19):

Ultrasonic: Don't output 255 when there is no chance of collision

olatoft, 2018-11-19:

Closed 2018-11-19.

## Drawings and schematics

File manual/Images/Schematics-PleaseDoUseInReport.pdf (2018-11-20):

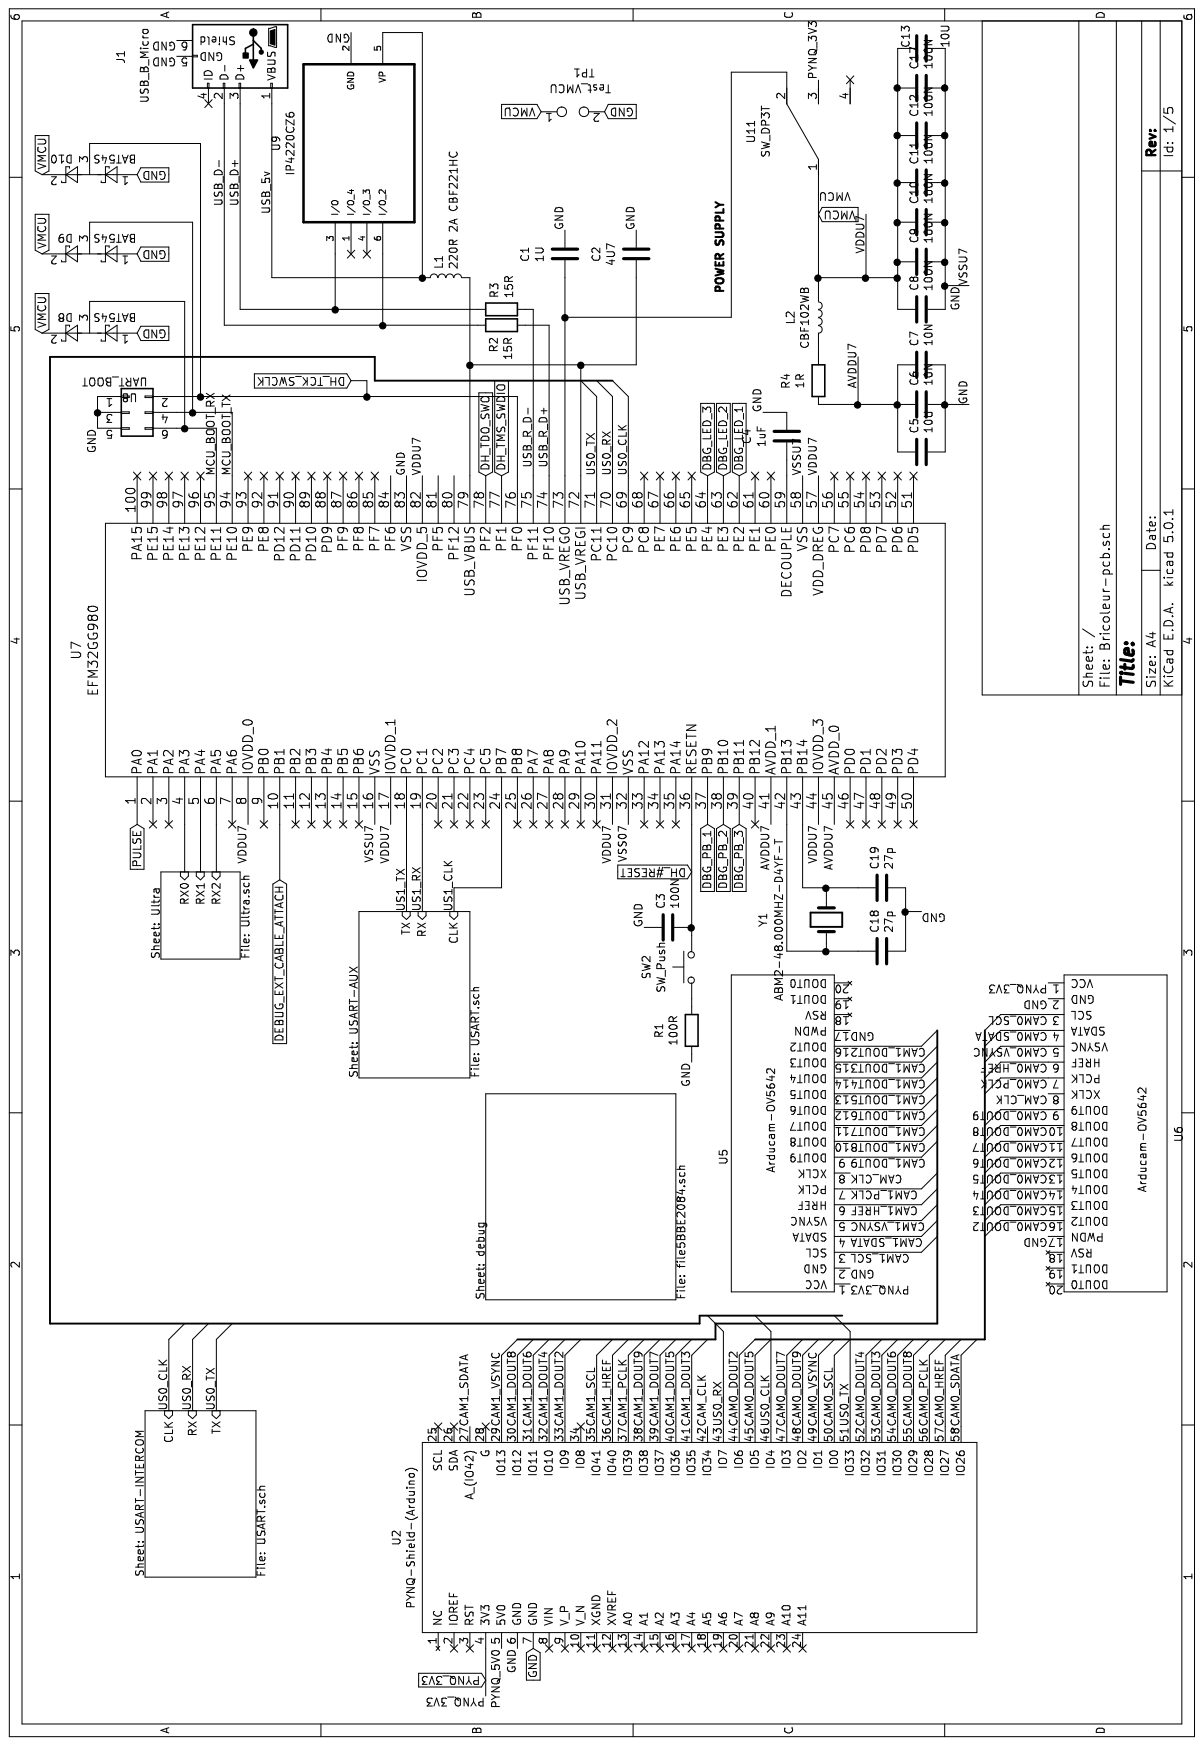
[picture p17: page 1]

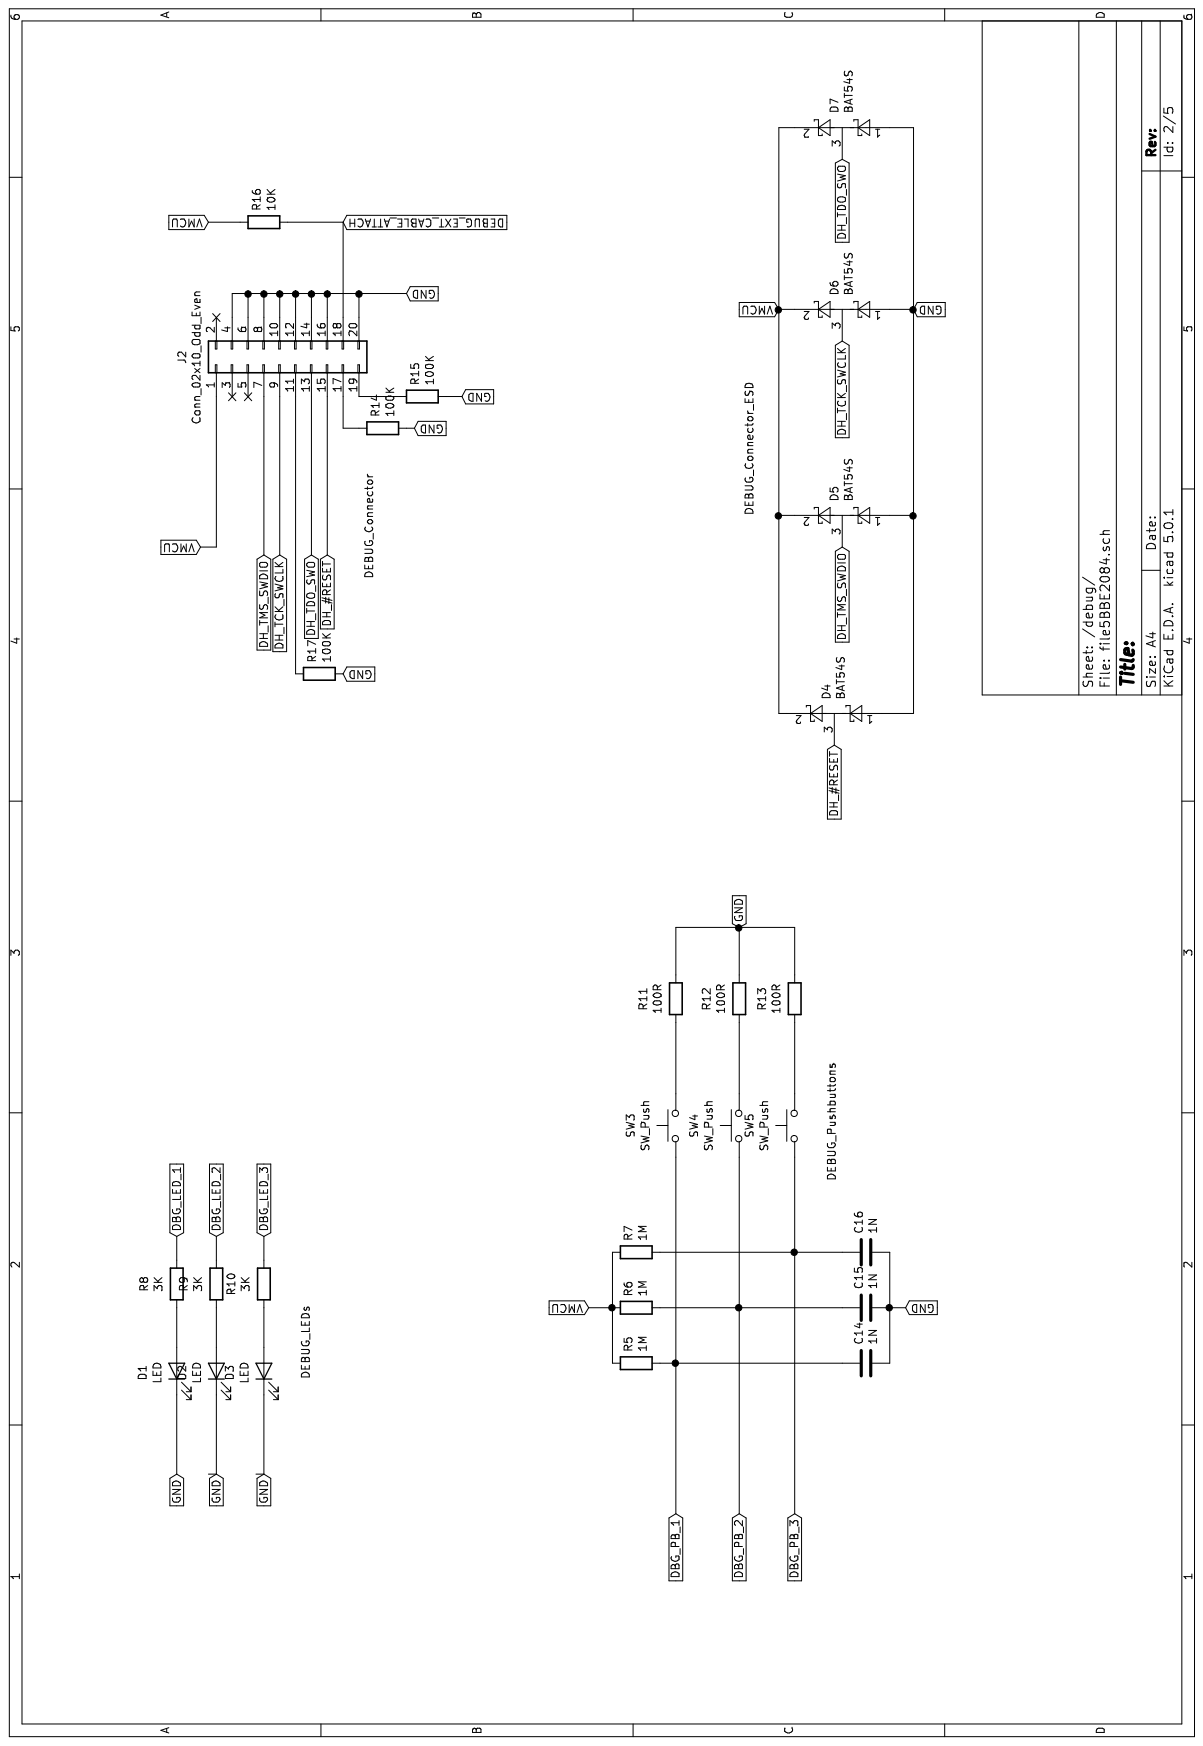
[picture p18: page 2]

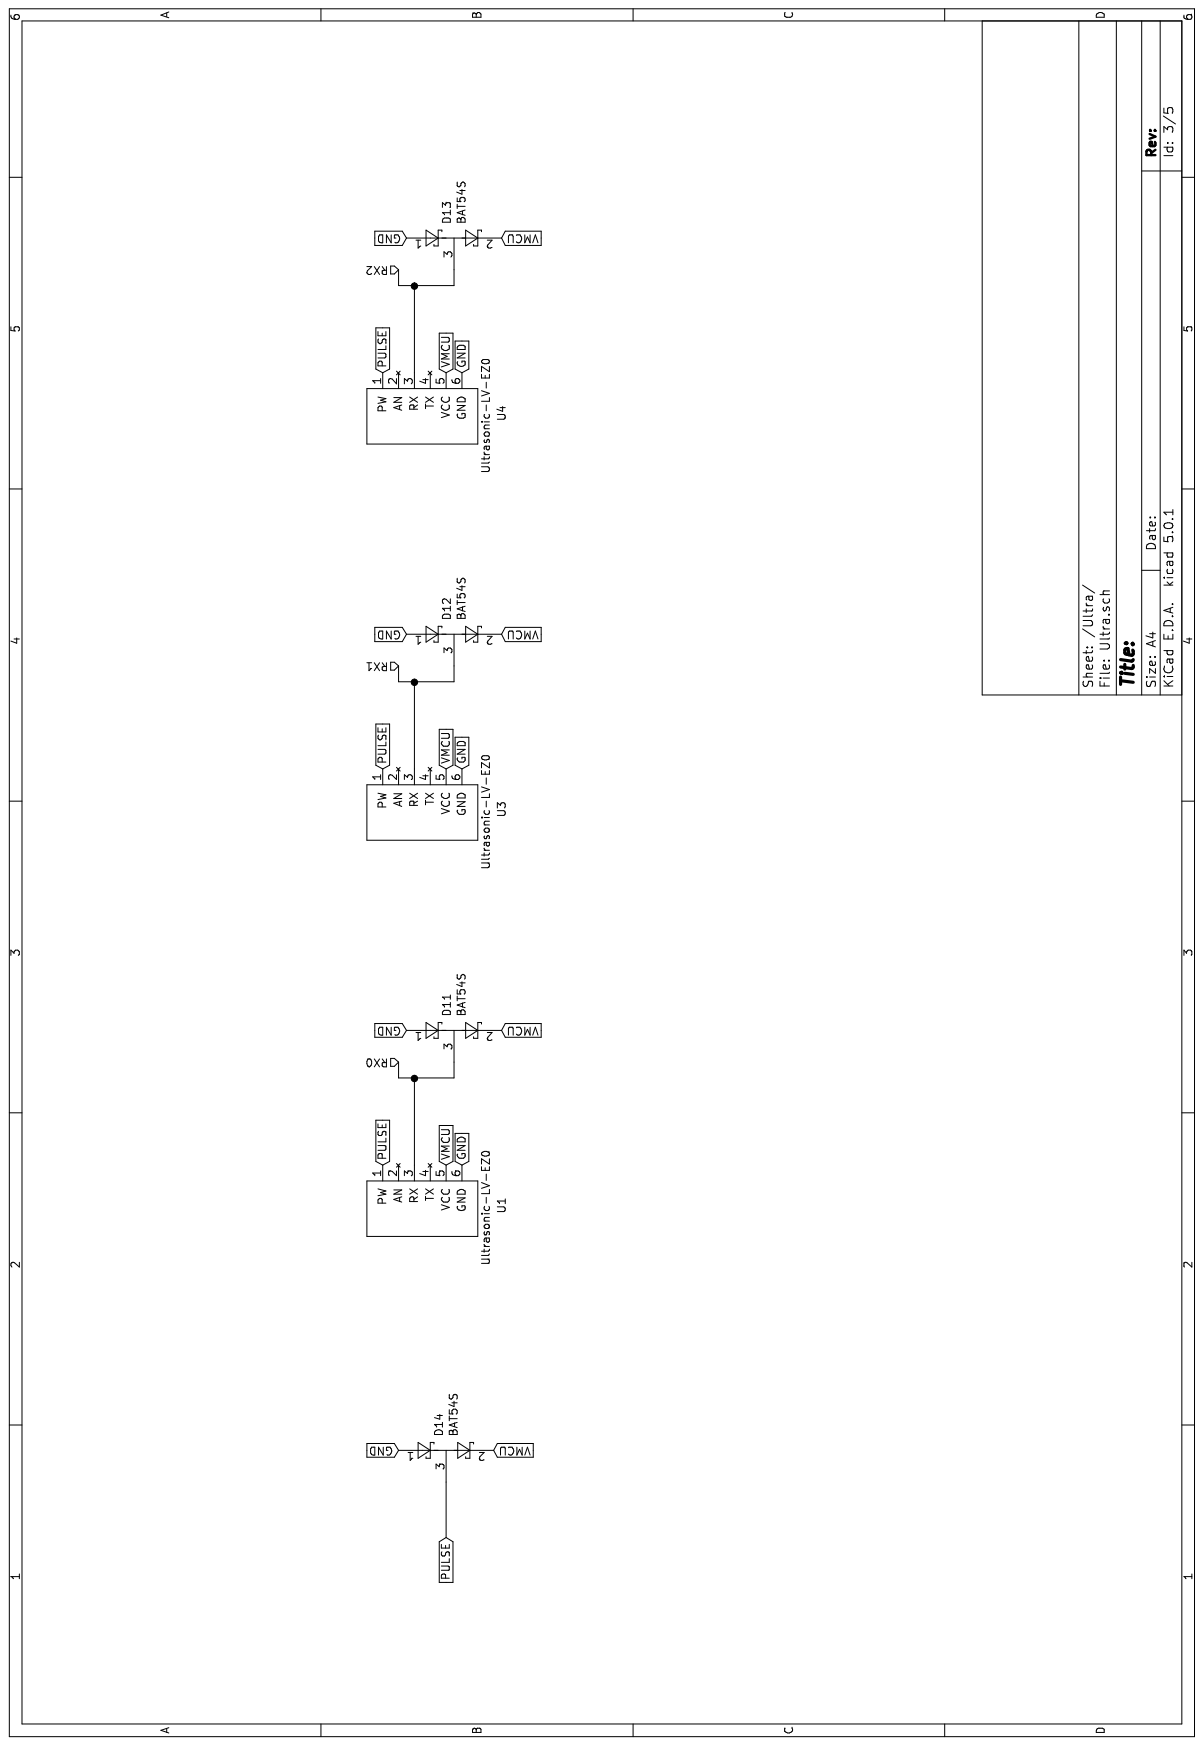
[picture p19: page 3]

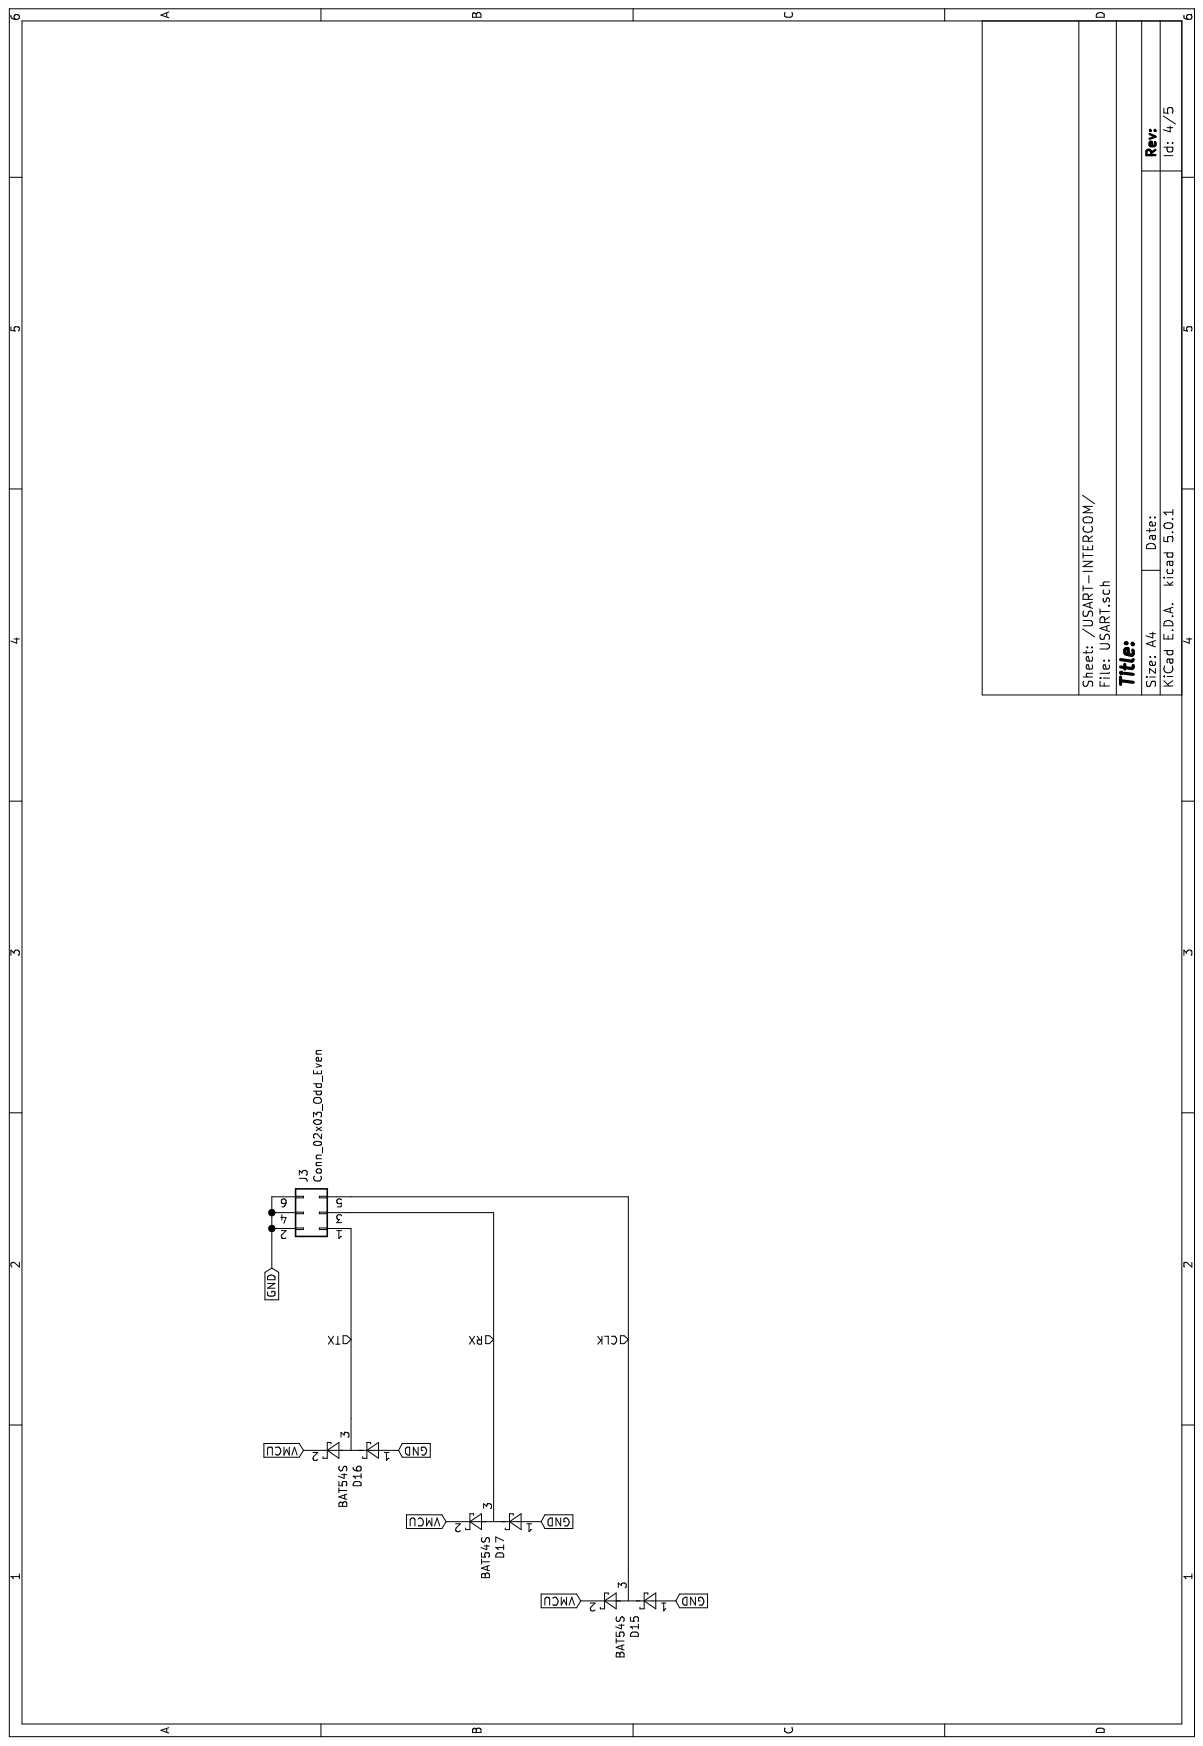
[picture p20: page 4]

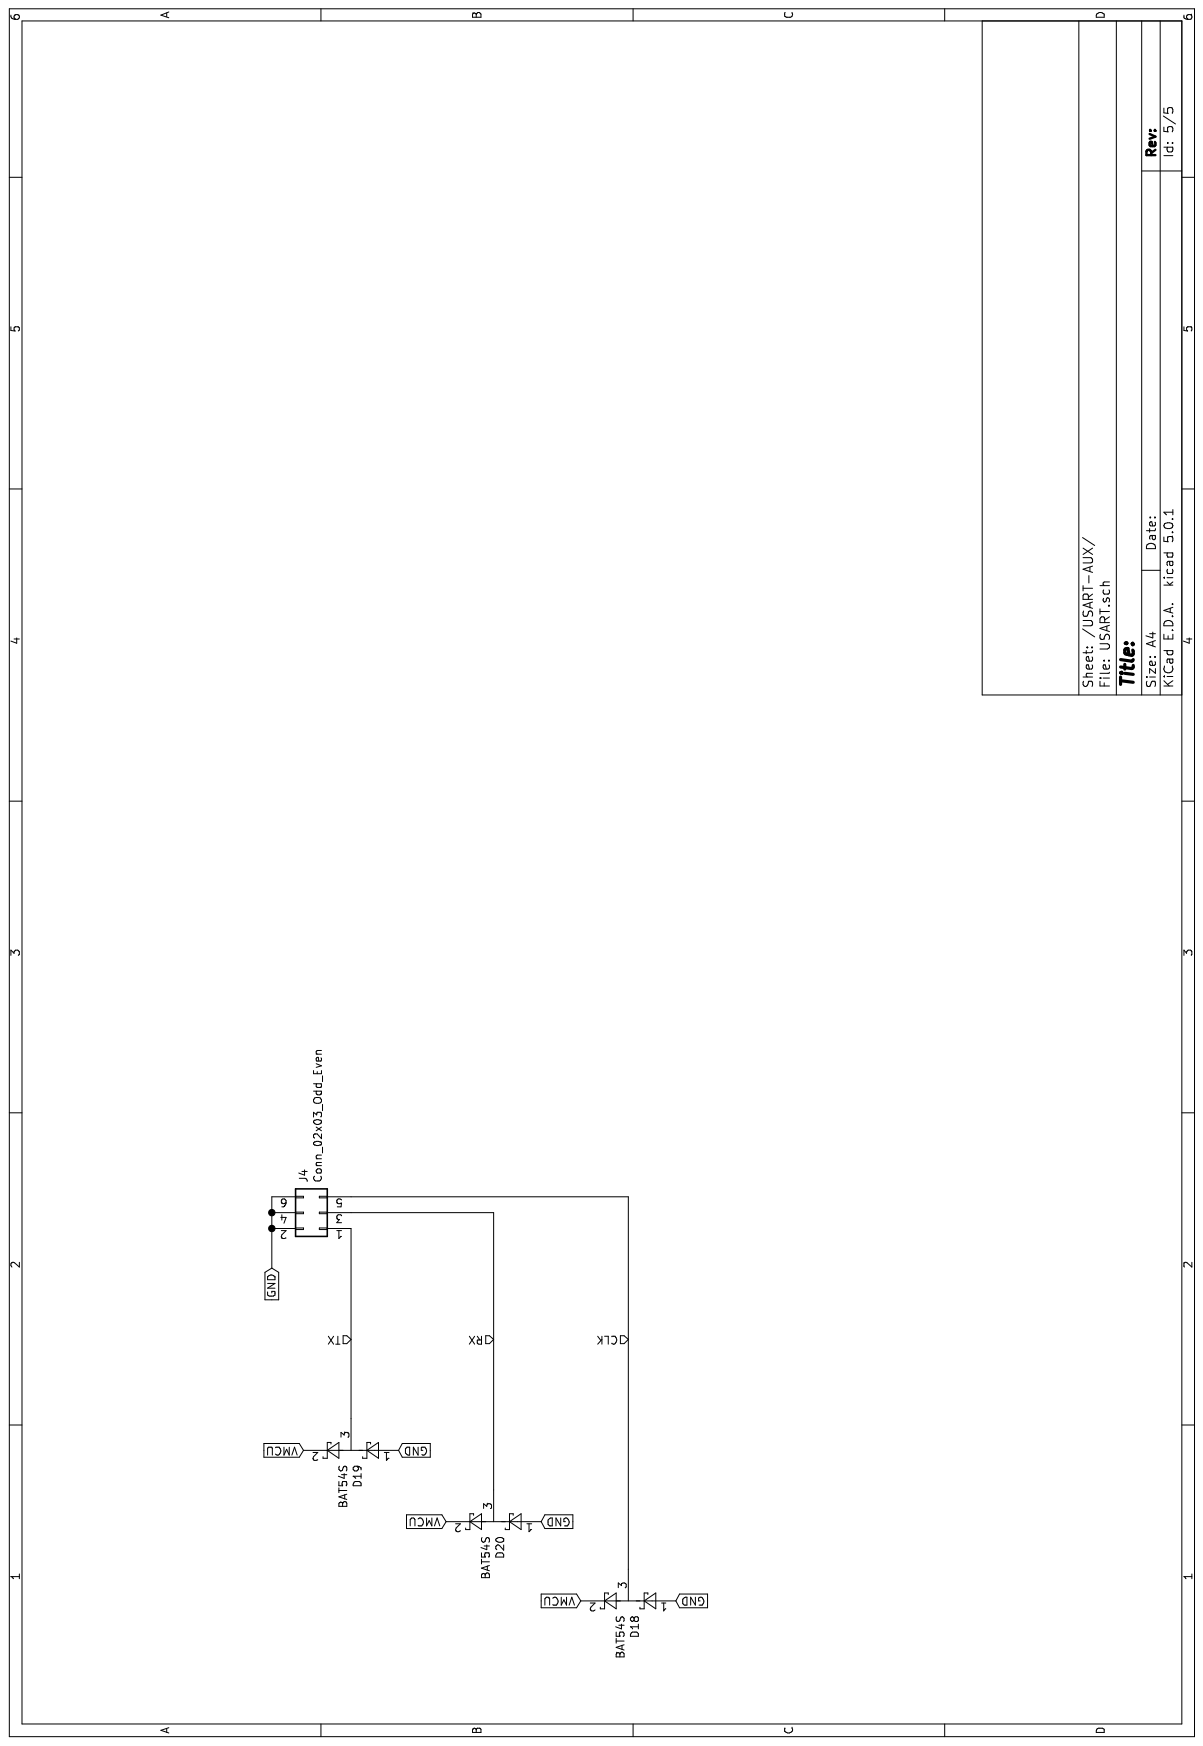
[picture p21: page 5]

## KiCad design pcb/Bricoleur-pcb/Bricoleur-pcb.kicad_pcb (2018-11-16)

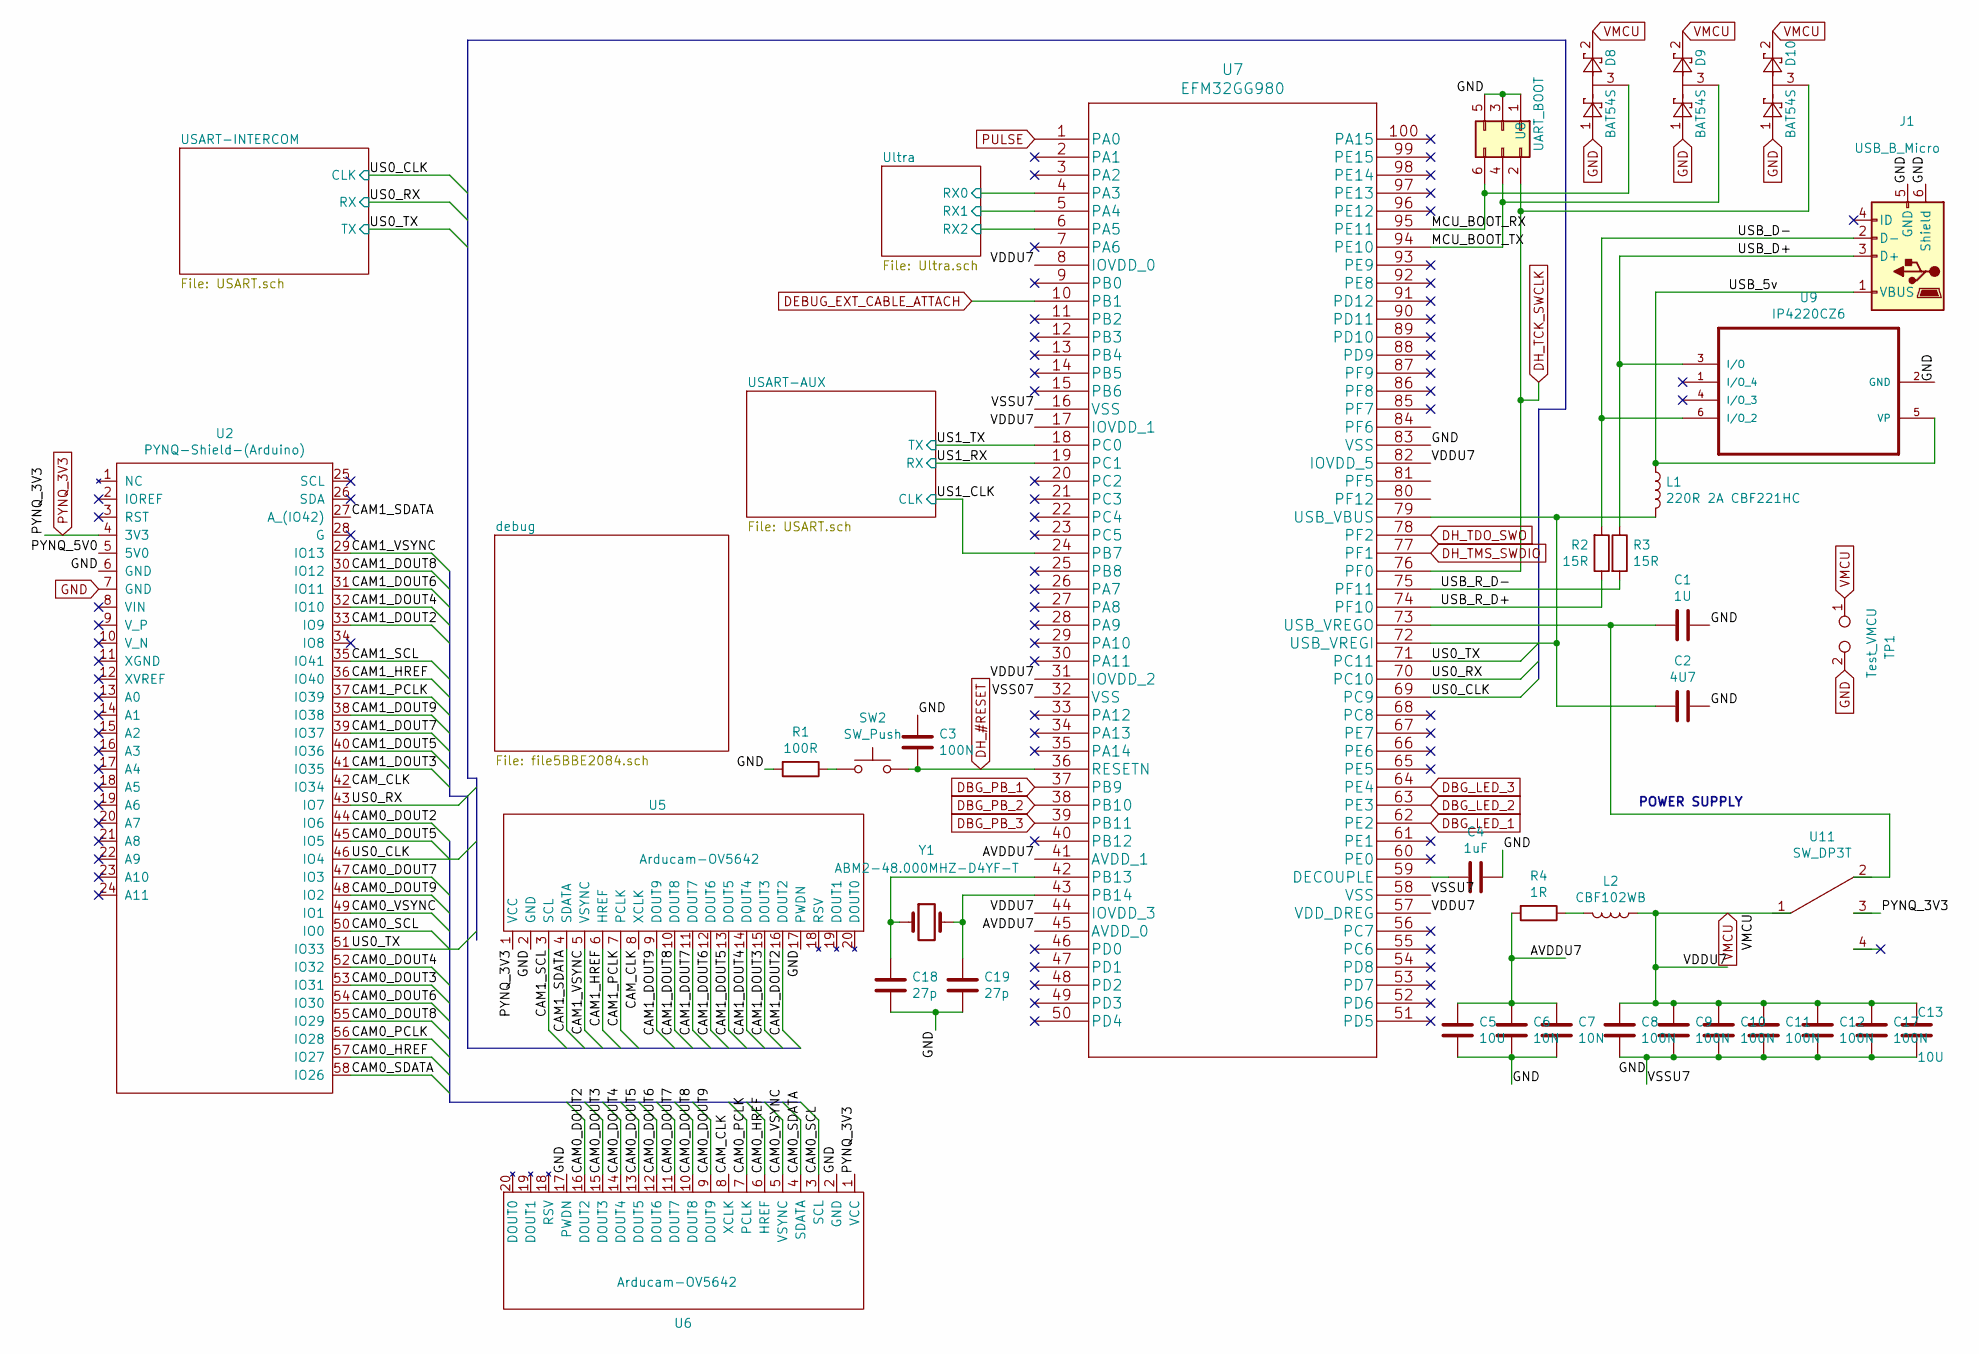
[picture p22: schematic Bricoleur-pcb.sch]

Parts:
C1: 1U; C_0201_0603Metric
C2: 4U7; C_0805_2012Metric
C3, C8, C9, C10, C11, C12, C17: 100N; C_0402_1005Metric
C4: 1uF; C_0603_1608Metric
C5, C13: 10U; C_0805_2012Metric
C6, C7: 10N; C_0402_1005Metric
C18, C19: 27p; C_0402_1005Metric
D8, D9, D10: BAT54S; SOT-23
J1: USB_B_Micro; USB_Micro-B_Amphenol_10103594-0001LF_Horizontal
L1: 220R 2A CBF221HC; CBF221HC
L2: CBF102WB
R1: 100R; R_0402_1005Metric
R2, R3: 15R; R_0402_1005Metric
R4: 1R; R_0402_1005Metric
SW2: SW_Push; SWITCH_WURTH_4301182043816
TP1: Test_VMCU; PinSocket_1x02_P2.54mm_Vertical
U2: PYNQ-Shield-(Arduino); PYNQ_Shield
U5, U6: Arducam-OV5642; IDC-Header_2x10_P2.54mm_Vertical
U7: EFM32GG980
U8: UART_BOOT; IDC-Header_2x03_P2.54mm_Vertical
U9: IP4220CZ6
U11: SW_DP3T; SW_CK_JS203011
Y1: ABM2-48.000MHZ-D4YF-T; XTAL

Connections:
/AVDDU7: C5.1, C6.1, C7.1, R4.2, U7.41 (AVDD_1), U7.45 (AVDD_0)
/CAM0_DOUT2: U2.44 (IO6), U6.16 (DOUT2)
/CAM0_DOUT3: U2.53 (IO31), U6.15 (DOUT3)
/CAM0_DOUT4: U2.52 (IO32), U6.14 (DOUT4)
/CAM0_DOUT5: U2.45 (IO5), U6.13 (DOUT5)
/CAM0_DOUT6: U2.54 (IO30), U6.12 (DOUT6)
/CAM0_DOUT7: U2.47 (IO3), U6.11 (DOUT7)
/CAM0_DOUT8: U2.55 (IO29), U6.10 (DOUT8)
/CAM0_DOUT9: U2.48 (IO2), U6.9 (DOUT9)
/CAM0_HREF: U2.57 (IO27), U6.6 (HREF)
/CAM0_PCLK: U2.56 (IO28), U6.7 (PCLK)
/CAM0_SCL: U2.50 (IO0), U6.3 (SCL)
/CAM0_SDATA: U2.58 (IO26), U6.4 (SDATA)
/CAM0_VSYNC: U2.49 (IO1), U6.5 (VSYNC)
/CAM1_DOUT2: U2.33 (IO9), U5.16 (DOUT2)
/CAM1_DOUT3: U2.41 (IO35), U5.15 (DOUT3)
/CAM1_DOUT4: U2.32 (IO10), U5.14 (DOUT4)
/CAM1_DOUT5: U2.40 (IO36), U5.13 (DOUT5)
/CAM1_DOUT6: U2.31 (IO11), U5.12 (DOUT6)
/CAM1_DOUT7: U2.39 (IO37), U5.11 (DOUT7)
/CAM1_DOUT8: U2.30 (IO12), U5.10 (DOUT8)
/CAM1_DOUT9: U2.38 (IO38), U5.9 (DOUT9)
/CAM1_HREF: U2.36 (IO40), U5.6 (HREF)
/CAM1_PCLK: U2.37 (IO39), U5.7 (PCLK)
/CAM1_SCL: U2.35 (IO41), U5.3 (SCL)
/CAM1_SDATA: U2.27 (A_(IO42)), U5.4 (SDATA)
/CAM1_VSYNC: U2.29 (IO13), U5.5 (VSYNC)
/CAM_CLK: U2.42 (IO34), U5.8 (XCLK), U6.8 (XCLK)
/Sheet5BB71F0E/INP: D8.3, U7.95 (PE11), U8.6
/US0_RX: U2.43 (IO7), U7.70 (PC10); also elsewhere on the board
/US1_RX: U7.19 (PC1); also elsewhere on the board
/USB_5v: J1.1 (VBUS), L1.1, U9.5 (VP)
/USB_D+: J1.3 (D+), R3.1, U9.3 (I/O)
/USB_D-: J1.2 (D-), R2.2, U9.6 (I/O_2)
/USB_R_D+: R2.1, U7.74 (PF10)
/USB_R_D-: R3.2, U7.75 (PF11)
/Ultra/RX0: U7.4 (PA3); also elsewhere on the board
/Ultra/RX1: U7.5 (PA4); also elsewhere on the board
/Ultra/RX2: U7.6 (PA5); also elsewhere on the board
/sheet5BB7B6EA/INP: D9.3, U7.94 (PE10), U8.4
DBG_LED_1: U7.62 (PE2); also elsewhere on the board
DBG_LED_2: U7.63 (PE3); also elsewhere on the board
DBG_LED_3: U7.64 (PE4); also elsewhere on the board
DBG_PB_1: U7.37 (PB9); also elsewhere on the board
DBG_PB_2: U7.38 (PB10); also elsewhere on the board
DBG_PB_3: U7.39 (PB11); also elsewhere on the board
DEBUG_EXT_CABLE_ATTACH: U7.10 (PB1); also elsewhere on the board
DH_#RESET: C3.2, SW2.2, U7.36 (RESETN); also elsewhere on the board
DH_TCK_SWCLK: D10.3, U7.76 (PF0), U8.2; also elsewhere on the board
DH_TDO_SWO: U7.78 (PF2); also elsewhere on the board
DH_TMS_SWDIO: U7.77 (PF1); also elsewhere on the board
GND: C1.1, C2.1, C3.1, C4.1, C5.2, C6.2, C7.2, C8.2, C9.2, C10.2, C11.2, C12.2, C13.2, C17.2, C18.2, C19.2, D8.1, D9.1, D10.1, J1.5 (GND), J1.6 (Shield), R1.2, TP1.2, U2.6 (GND), U2.7 (GND), U5.2 (GND), U5.17 (PWDN), U6.2 (GND), U6.17 (PWDN), U7.16 (VSS), U7.58 (VSS), U7.83 (VSS), U8.1, U8.3, U8.5, U9.2 (GND); also elsewhere on the board
unnamed: C1.2, U7.73 (USB_VREGO), U11.2
unnamed: C2.2, L1.2, U7.72 (USB_VREGI), U7.79 (USB_VBUS)
unnamed: C4.2, U7.59 (DECOUPLE)
unnamed: C18.1, U7.42 (PB13), Y1.1
unnamed: C19.1, U7.43 (PB14), Y1.2
unnamed: L2.2, R4.1
unnamed: R1.1, SW2.1
PULSE: U7.1 (PA0); also elsewhere on the board
PYNQ_3V3: U2.4 (3V3), U5.1 (VCC), U6.1 (VCC), U11.3
VMCU: C8.1, C9.1, C10.1, C11.1, C12.1, C13.1, C17.1, D8.2, D9.2, D10.2, L2.1, TP1.1, U7.8 (IOVDD_0), U7.17 (IOVDD_1), U7.31 (IOVDD_2), U7.44 (IOVDD_3), U7.57 (VDD_DREG), U7.82 (IOVDD_5), U11.1; also elsewhere on the board

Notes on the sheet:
POWER SUPPLY

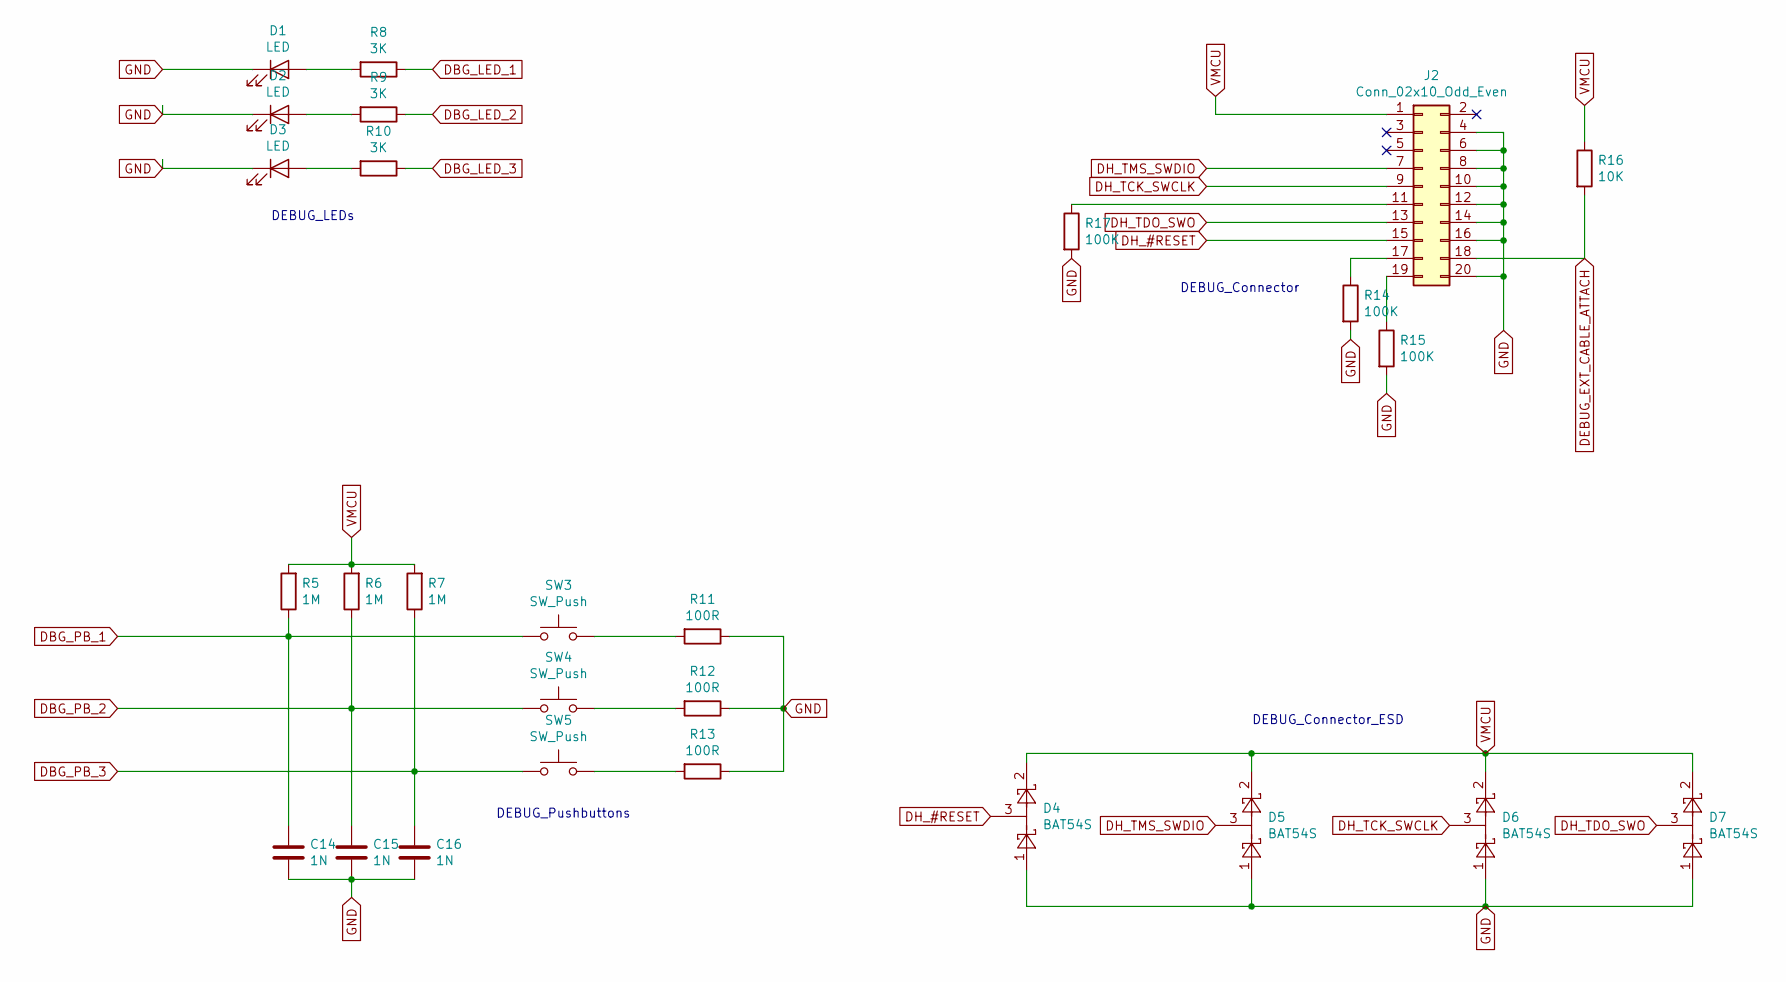
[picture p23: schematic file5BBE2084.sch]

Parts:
C14, C15, C16: 1N; C_0402_1005Metric
D1, D2, D3: LED; LED_0201_0603Metric
D4, D5, D6, D7: BAT54S; SOT-23
J2: Conn_02x10_Odd_Even; IDC-Header_2x10_P2.54mm_Vertical
R5, R6, R7: 1M; R_0402_1005Metric
R8: 3K; R_0402_1005Metric
R9, R10: 3K; C_0402_1005Metric
R11, R12, R13: 100R; R_0402_1005Metric
R14, R15, R17: 100K; R_0402_1005Metric
R16: 10K; R_0402_1005Metric
SW3, SW4, SW5: SW_Push; SWITCH_WURTH_4301182043816

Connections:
DBG_LED_1: R8.1; also elsewhere on the board
DBG_LED_2: R9.1; also elsewhere on the board
DBG_LED_3: R10.1; also elsewhere on the board
DBG_PB_1: C14.1, R5.1, SW3.1; also elsewhere on the board
DBG_PB_2: C15.1, R6.1, SW4.1; also elsewhere on the board
DBG_PB_3: C16.1, R7.1, SW5.1; also elsewhere on the board
DEBUG_EXT_CABLE_ATTACH: J2.18, R16.2; also elsewhere on the board
DH_#RESET: D4.3, J2.15; also elsewhere on the board
DH_TCK_SWCLK: D6.3, J2.9; also elsewhere on the board
DH_TDO_SWO: D7.3, J2.13; also elsewhere on the board
DH_TMS_SWDIO: D5.3, J2.7; also elsewhere on the board
GND: C14.2, C15.2, C16.2, D1.1 (K), D2.1 (K), D3.1 (K), D4.1, D5.1, D6.1, D7.1, J2.4, J2.6, J2.8, J2.10, J2.12, J2.14, J2.16, J2.20, R11.1, R12.1, R13.1, R14.2, R15.2, R17.2; also elsewhere on the board
unnamed: D1.2 (A), R8.2
unnamed: D2.2 (A), R9.2
unnamed: D3.2 (A), R10.2
unnamed: J2.11, R17.1
unnamed: J2.17, R14.1
unnamed: J2.19, R15.1
unnamed: R11.2, SW3.2
unnamed: R12.2, SW4.2
unnamed: R13.2, SW5.2
VMCU: D4.2, D5.2, D6.2, D7.2, J2.1, R5.2, R6.2, R7.2, R16.1; also elsewhere on the board

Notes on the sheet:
DEBUG_LEDs
DEBUG_Pushbuttons
DEBUG_Connector
DEBUG_Connector_ESD

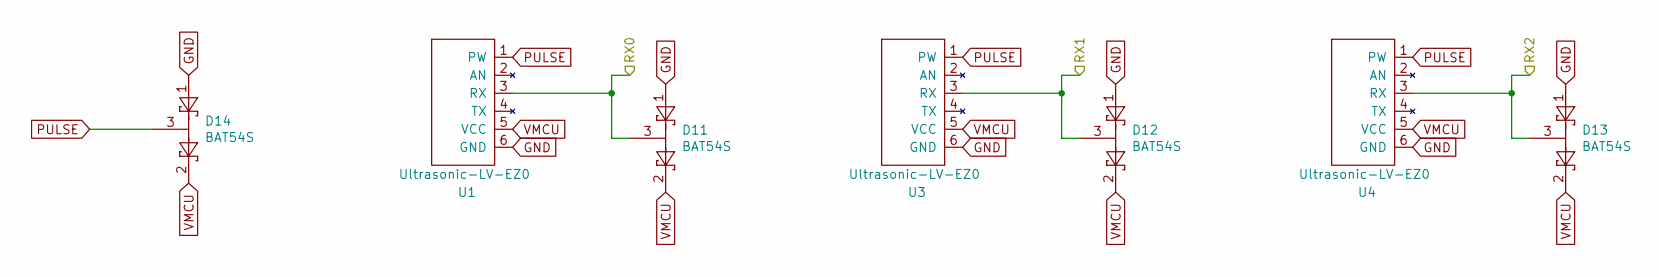
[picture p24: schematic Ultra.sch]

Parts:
D11, D12, D13, D14: BAT54S; SOT-23
U1, U3, U4: Ultrasonic-LV-EZ0; IDC-Header_2x03_P2.54mm_Vertical

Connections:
/Ultra/RX0: D11.3, U1.3 (RX); also elsewhere on the board
/Ultra/RX1: D12.3, U3.3 (RX); also elsewhere on the board
/Ultra/RX2: D13.3, U4.3 (RX); also elsewhere on the board
GND: D11.1, D12.1, D13.1, D14.1, U1.6 (GND), U3.6 (GND), U4.6 (GND); also elsewhere on the board
PULSE: D14.3, U1.1 (PW), U3.1 (PW), U4.1 (PW); also elsewhere on the board
VMCU: D11.2, D12.2, D13.2, D14.2, U1.5 (VCC), U3.5 (VCC), U4.5 (VCC); also elsewhere on the board

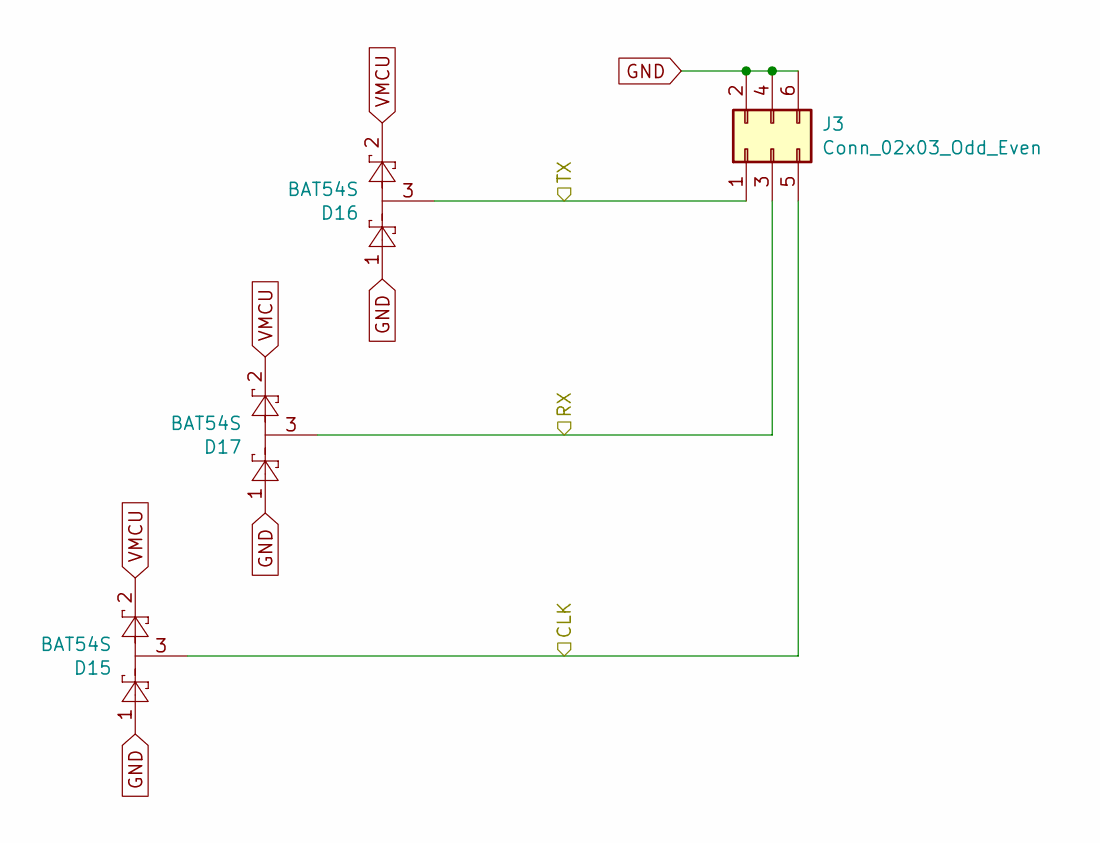
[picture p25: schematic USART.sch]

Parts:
D17, D18, D19: BAT54S; SOT-23
J3: Conn_02x03_Odd_Even; IDC-Header_2x03_P2.54mm_Vertical

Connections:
/US0_RX: D17.3, J3.3; also elsewhere on the board
GND: D17.1, D18.1, D19.1, J3.2, J3.4, J3.6; also elsewhere on the board
VMCU: D17.2, D18.2, D19.2; also elsewhere on the board

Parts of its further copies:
D15, D16, D20: BAT54S; SOT-23
J4: Conn_02x03_Odd_Even; IDC-Header_2x03_P2.54mm_Vertical

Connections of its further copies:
/US1_RX: D20.3, J4.3; also elsewhere on the board
GND: D15.1, D16.1, D20.1, J4.2, J4.4, J4.6; also elsewhere on the board
VMCU: D15.2, D16.2, D20.2; also elsewhere on the board

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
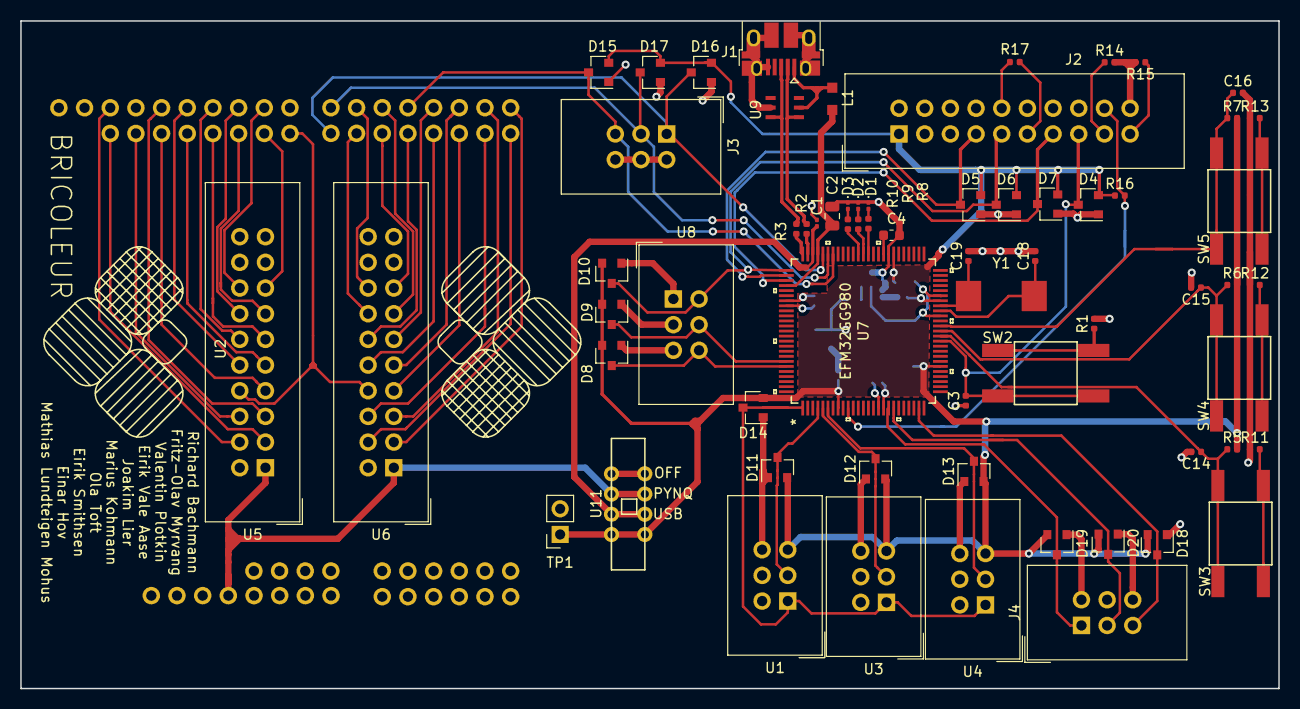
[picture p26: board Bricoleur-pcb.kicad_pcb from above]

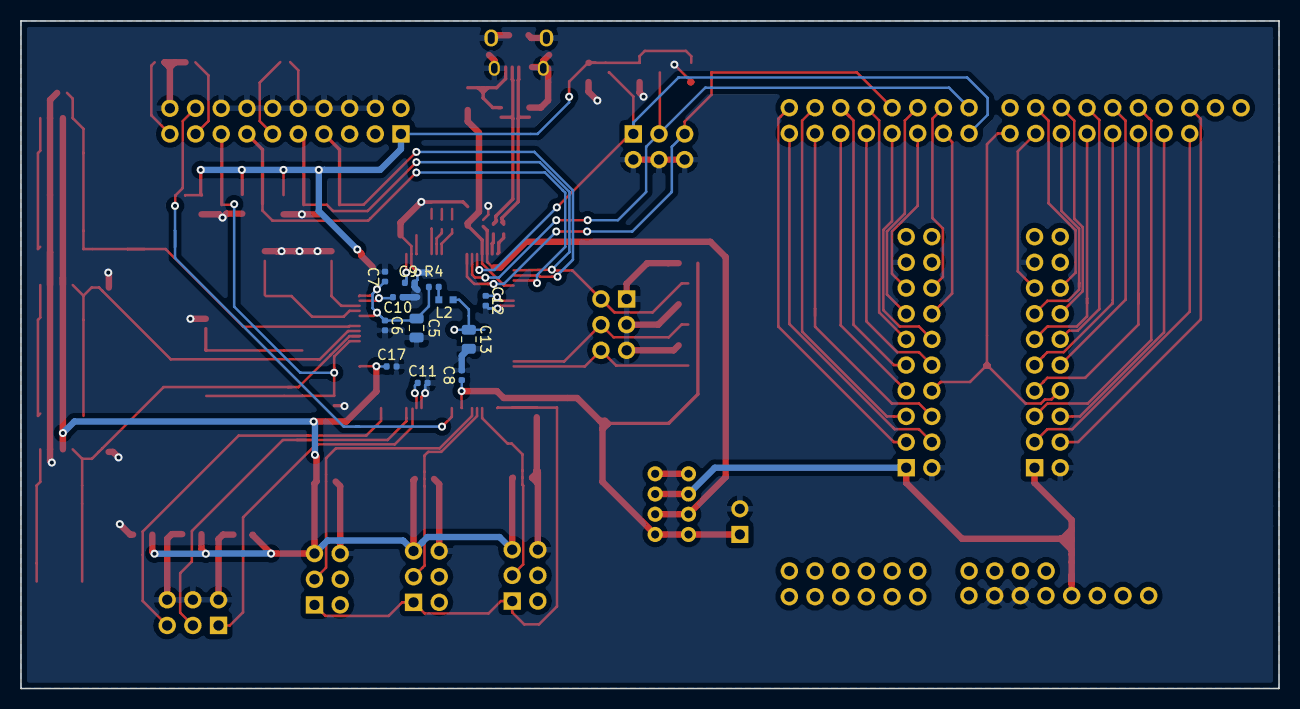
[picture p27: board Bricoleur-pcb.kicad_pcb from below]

Board: 2 copper layers, 124.5 x 66.0 mm, 78 parts (12 on the bottom side), 75 nets.

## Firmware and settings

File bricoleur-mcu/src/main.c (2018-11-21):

/*******************************************************************************
 * @file
 * @brief Bricoleur MCU 
 * @author Energy Micro AS
 * @version 3.20.2
 *******************************************************************************
 * @section License
 * <b>(C) Copyright 2014 Silicon Labs, http://www.silabs.com</b>
 *******************************************************************************
 *
 * This file is licensed under the Silicon Labs Software License Agreement. See 
 * "http://developer.silabs.com/legal/version/v11/Silicon_Labs_Software_License_Agreement.txt"  
 * for details. Before using this software for any purpose, you must agree to the 
 * terms of that agreement.
 *
 ******************************************************************************/

#include "stdio.h"
#include "string.h"
#include "em_device.h"
#include "em_chip.h"
#include "em_usart.h"
#include "em_cmu.h"
#include "em_gpio.h"
#include "bricoleur.h"
#include "main.h"
#include "ultrasonic.h"

// TODO: Check out DMA setup?
// TODO: I don't really know what I want to do with the receive buffers
// TODO: Sensor analysis code
// TODO: Make the whole process less stop and wait
// TODO: test

/*******************************************************************************
 * Structure
 ******************************************************************************/
/*
 Do MCU main operations here.
 PCB and project specific values go to bicoleur.h.
 Sensor specific operations go to sensors.c and .h 
*/

/*******************************************************************************
 * Config
 ******************************************************************************/
// Place values for quick tweaking here. 

/* Sensor analysis
 ****************/
#define numberOfSensors 2

/* USART transmission
 *******************/
#define outStringMaxLen 64
#define recvBuffMaxLen 64  // Must be the same as in bricoleur.h
#define recvTimeout 100

/* Debug LED interpretation
 * What do those blinking lights mean?
 ************************************/
 
/* 
 * 1) On when transmitting on USART
 * 2) On when receiving on USART

 */

/* Debug pushbutton actions
 *************************/



/*******************************************************************************
 * Definitions
 ******************************************************************************/

unsigned int wallDistances[numberOfSensors];

void set_dbg_LED(int LEDNum, bool on) {
    if (on) {   
        GPIO_PinModeSet(DBG_LED_PORT, LEDNum, gpioModePushPull, 1);
    } else {
        GPIO_PinOutClear(DBG_LED_PORT, LEDNum);
    }
}

void do_usart_setup() {
    /* USART is a HFPERCLK peripheral. Enable HFPERCLK domain and USART1.
     * We also need to enable the clock for GPIO to configure pins. */
    CMU_ClockEnable(cmuClock_HFPER, true);
    CMU_ClockEnable(cmuClock_GPIO, true);

    /*
     * Setup for USART1 / USART-AUX as UART
     */
  
    CMU_ClockEnable(cmuClock_USART1, true);
    // Asynchronous
    USART_InitAsync_TypeDef initAsync1 = USART_INITASYNC_DEFAULT;
    initAsync1.baudrate = 115200;
    USART_InitAsync(USART1, &initAsync1);

    /* Pin numbers:
     * Name             MCU    EXP
     * USART1_TX	PC0
     * USART1_RX	PC1
     * USART1_CLK	PB7
     * USART1_CS	PB8    (UNUSED)
     */

    /* Enable I/O and set location */
    USART1->ROUTE = USART_ROUTE_RXPEN | USART_ROUTE_TXPEN | USART_AUX_LOC;
    /* Set GPIO mode. */
    GPIO_PinModeSet((GPIO_Port_TypeDef)AF_USART1_TX_PORT(USART_AUX_PORTNUM),
       AF_USART1_TX_PIN(USART_AUX_PORTNUM), gpioModePushPull, 1);
    GPIO_PinModeSet((GPIO_Port_TypeDef)AF_USART1_RX_PORT(USART_AUX_PORTNUM), 
      AF_USART1_RX_PIN(USART_AUX_PORTNUM), gpioModeInput, 0);
}

void do_pynq_setup() {
    /*
     * Setup for PYNQ communication
     */
  
    /* Pin numbers:
     * Name             MCU    EXP
     * USART1_TX	PC11
     * USART1_RX	PC10
     * USART1_CLK	PC9
     * USART1_CS	PC8    (UNUSED)
     */

    /* Enable I/O and set location */
    GPIO_PinModeSet(USART_FPGA_PORT, USART_FPGA_TX, gpioModeInputPull, 0);
    GPIO_PinModeSet(USART_FPGA_PORT, USART_FPGA_RX, gpioModeInputPull, 0);
    GPIO_PinModeSet(USART_FPGA_PORT, USART_FPGA_CLK, gpioModeInputPull, 0);
}

void USART_send(USART_TypeDef *usart, char *string) {
    /* Send a string on the given USART.
     * USART_Tx calls will stall if TX buffer is full,
     * which means that this function blocks until sending is completed.
     */
    set_dbg_LED(1, true); 
    for (int i = 0; string[i] != '\0'; i++) {
        USART_Tx(usart, string[i]);
    }
    set_dbg_LED(1, false);
}

int USART_recv(USART_TypeDef *usart, USART_Buffer *buffer, int abort) {
    /* Receive a frame of data on the given USART. 
     * Blocks until a full frame has arrived.
     * Returns number of received bytes.
     */

    int abortCount = abort;  // Safety in case endstring character never arrives
   
    set_dbg_LED(2, true);

    // Reset buffer, overwrite old data
    buffer->head = 0;
    buffer->tail = buffer->head;
    buffer->length = 0;
    buffer->wrapped = false;

    // Skip incomplete frames
    char readVal;
    readVal = USART_Rx(usart);
    while(readVal != '\0') {
        readVal = USART_Rx(usart);
        // Safeguard to prevent deadlock? What if \0 never arrives?
        if (--abortCount <= 0) {
            break; 
        }
    }
    
    // Reset abortCount
    abortCount = abort;
  
    // Write complete frame to buffer
    do {
        readVal = USART_Rx(usart);
        (buffer->data)[buffer->tail++] = readVal;
        buffer->length++;
        if (buffer->tail == buffer->head) {
            // Transmitted frame was too large
            buffer->wrapped = true;
        }

        // Safeguard to prevent deadlock? What if \0 never arrives?
        if (--abortCount >= 0) {
            break; 
        }

    }  while(readVal != '\0');

    // Return with negative number if buffer overflowed
    if (buffer->wrapped) {
        return -1;
    }     
    
    set_dbg_LED(2, false);
    return buffer->length;
}

void createCommand(USART_Buffer *input, char *outString) {
    // Determine appropriate message to AUX device (can be 1:1 copy of input)
    
    // Placeholder while protocol is unknown
    *outString = strdup(input->data);
}

// Scale linearly
uint8_t localToGlobalConclusion(float input, float inputMin, float inputMax, float outputMin, float outputMax) {
	float slope = 1.0 * (outputMax - outputMin) / (inputMax - inputMin);
	return (uint8_t)(outputMin + slope * (input - inputMin));
}

// @cameraWeight: Number between 0 and 1 indicating how much the cameraConclusion should be weighted.
uint8_t getCombinedConclusion(uint8_t cameraConclusion, uint8_t ultrasonicConclusion) {
	if (cameraConclusion > ultrasonicConclusion) {
		return cameraConclusion;
	} else {
		return ultrasonicConclusion;
	}
}

/**************************************************************************//**
 * @brief  Main function
 *****************************************************************************/
int main(void) {
    /* Chip errata, setup and calibration */
    CHIP_Init();
    do_usart_setup();
    do_pynq_setup();


	Buffer buffer;
	setupUltrasonic(&buffer);

	Position positions[buffer.maxLength];

	unsigned int previousDistances[numberOfSensors];


    // PCB: L2 er 220nH i stedet for 1000

    /* Define some buffers for receiving and sending data */

    USART_Buffer ULTRA_Buf = {
        .head = 0,
        .tail = 0, 
        .length = 0, 
        .maxLength = recvBuffMaxLen, 
        .wrapped = false, 
    };

    set_dbg_LED(2, true);

    /* Infinite loop */
    while (1) {
        /* Protocol for PYNQ and external device communication */

        // Read sensor data sequentially from active sensors

        // Perform sensor analysis
        // Local conclusion is the conclusion in a scale defined by the ultrasonic system (0 to 1)
        // Global conclusion is the local conclusion mapped to a scale which will be used by the imponator
        float ultrasonicLocalConclusion = getUltrasonicLocalConclusion(&buffer, positions, previousDistances);
        uint8_t ultrasonicGlobalConclusion = localToGlobalConclusion(ultrasonicLocalConclusion, 0, 1, 0, 255);

//        char stringBuffer[50];
//		snprintf(stringBuffer, 49, "conclusion: %u\n", ultrasonicGlobalConclusion);
//
//		for (int i = 0; stringBuffer[i] != '\0'; i++) {
//			USART_Tx(USART1, stringBuffer[i]);
//		}

        // End sensor reading line
//        USART_Tx(USART1, '\n');

        uint8_t bit0 = GPIO_PinInGet(USART_FPGA_PORT, USART_FPGA_TX);
        uint8_t bit1 = GPIO_PinInGet(USART_FPGA_PORT, USART_FPGA_RX);
        uint8_t bit2 = GPIO_PinInGet(USART_FPGA_PORT, USART_FPGA_CLK);

        // Local conclusion from camera system: Value between 0 and 7
        // Indicates chance of collision, where 7 is largest chance of collision
        // Based on whether an object is moving towards us or not
        uint8_t pynq_data = bit2 * 4 + bit1 * 2 + bit0;
        uint8_t cameraGlobalConclusion = localToGlobalConclusion(pynq_data, 0, 7, 0, 255);

        uint8_t combinedConclusion = getCombinedConclusion(cameraGlobalConclusion, ultrasonicGlobalConclusion);

        USART_Tx(USART1, combinedConclusion);
//        USART_Tx(USART1, '\n');

        /*

        // Interpret PYNQ output data, translate to external command
        createCommand(&FPGA_Rx_Buf, AUX_Tx_String);

        // Output new instruction to external device
        USART_send(USART1, AUX_Tx_String); // Forward FPGA instructions to device
        */
    }
}

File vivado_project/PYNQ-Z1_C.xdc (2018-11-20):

## This file is a general .xdc for the PYNQ-Z1 board Rev. C
## To use it in a project:
## - uncomment the lines corresponding to used pins
## - rename the used ports (in each line, after get_ports) according to the top level signal names in the project

## Clock signal 125 MHz

#set_property -dict { PACKAGE_PIN H16   IOSTANDARD LVCMOS33 } [get_ports { sysclk }]; #IO_L13P_T2_MRCC_35 Sch=sysclk
#create_clock -add -name sys_clk_pin -period 8.00 -waveform {0 4} [get_ports { sysclk }];

##Switches

#set_property -dict { PACKAGE_PIN M20   IOSTANDARD LVCMOS33 } [get_ports { switch }]; #IO_L7N_T1_AD2N_35 Sch=sw[0]
#set_property -dict { PACKAGE_PIN M19   IOSTANDARD LVCMOS33 } [get_ports { sw[1] }]; #IO_L7P_T1_AD2P_35 Sch=sw[1]

##RGB LEDs

#set_property -dict { PACKAGE_PIN L15   IOSTANDARD LVCMOS33 } [get_ports { led4_b }]; #IO_L22N_T3_AD7N_35 Sch=led4_b
#set_property -dict { PACKAGE_PIN G17   IOSTANDARD LVCMOS33 } [get_ports { led4_g }]; #IO_L16P_T2_35 Sch=led4_g
#set_property -dict { PACKAGE_PIN N15   IOSTANDARD LVCMOS33 } [get_ports { led4_r }]; #IO_L21P_T3_DQS_AD14P_35 Sch=led4_r
#set_property -dict { PACKAGE_PIN G14   IOSTANDARD LVCMOS33 } [get_ports { led5_b }]; #IO_0_35 Sch=led5_b
#set_property -dict { PACKAGE_PIN L14   IOSTANDARD LVCMOS33 } [get_ports { led5_g }]; #IO_L22P_T3_AD7P_35 Sch=led5_g
#set_property -dict { PACKAGE_PIN M15   IOSTANDARD LVCMOS33 } [get_ports { led5_r }]; #IO_L23N_T3_35 Sch=led5_r

##LEDs

#set_property -dict { PACKAGE_PIN R14   IOSTANDARD LVCMOS33 } [get_ports { LED }]; #IO_L6N_T0_VREF_34 Sch=led[0]
#set_property -dict { PACKAGE_PIN P14   IOSTANDARD LVCMOS33 } [get_ports { led[1] }]; #IO_L6P_T0_34 Sch=led[1]
#set_property -dict { PACKAGE_PIN N16   IOSTANDARD LVCMOS33 } [get_ports { led[2] }]; #IO_L21N_T3_DQS_AD14N_35 Sch=led[2]
#set_property -dict { PACKAGE_PIN M14   IOSTANDARD LVCMOS33 } [get_ports { led[3] }]; #IO_L23P_T3_35 Sch=led[3]

##Buttons

#set_property -dict { PACKAGE_PIN D19   IOSTANDARD LVCMOS33 } [get_ports { btn[0] }]; #IO_L4P_T0_35 Sch=btn[0]
#set_property -dict { PACKAGE_PIN D20   IOSTANDARD LVCMOS33 } [get_ports { btn[1] }]; #IO_L4N_T0_35 Sch=btn[1]
#set_property -dict { PACKAGE_PIN L20   IOSTANDARD LVCMOS33 } [get_ports { btn[2] }]; #IO_L9N_T1_DQS_AD3N_35 Sch=btn[2]
#set_property -dict { PACKAGE_PIN L19   IOSTANDARD LVCMOS33 } [get_ports { btn[3] }]; #IO_L9P_T1_DQS_AD3P_35 Sch=btn[3]

##Pmod Header JA

#set_property -dict { PACKAGE_PIN Y18   IOSTANDARD LVCMOS33 } [get_ports { ja[0] }]; #IO_L17P_T2_34 Sch=ja_p[1]
#set_property -dict { PACKAGE_PIN Y19   IOSTANDARD LVCMOS33 } [get_ports { ja[1] }]; #IO_L17N_T2_34 Sch=ja_n[1]
#set_property -dict { PACKAGE_PIN Y16   IOSTANDARD LVCMOS33 } [get_ports { ja[2] }]; #IO_L7P_T1_34 Sch=ja_p[2]
#set_property -dict { PACKAGE_PIN Y17   IOSTANDARD LVCMOS33 } [get_ports { ja[3] }]; #IO_L7N_T1_34 Sch=ja_n[2]
#set_property -dict { PACKAGE_PIN U18   IOSTANDARD LVCMOS33 } [get_ports { ja[4] }]; #IO_L12P_T1_MRCC_34 Sch=ja_p[3]
#set_property -dict { PACKAGE_PIN U19   IOSTANDARD LVCMOS33 } [get_ports { ja[5] }]; #IO_L12N_T1_MRCC_34 Sch=ja_n[3]
#set_property -dict { PACKAGE_PIN W18   IOSTANDARD LVCMOS33 } [get_ports { ja[6] }]; #IO_L22P_T3_34 Sch=ja_p[4]
#set_property -dict { PACKAGE_PIN W19   IOSTANDARD LVCMOS33 } [get_ports { ja[7] }]; #IO_L22N_T3_34 Sch=ja_n[4]

##Pmod Header JB

#set_property -dict { PACKAGE_PIN W14   IOSTANDARD LVCMOS33 } [get_ports { jb[0] }]; #IO_L8P_T1_34 Sch=jb_p[1]
#set_property -dict { PACKAGE_PIN Y14   IOSTANDARD LVCMOS33 } [get_ports { jb[1] }]; #IO_L8N_T1_34 Sch=jb_n[1]
#set_property -dict { PACKAGE_PIN T11   IOSTANDARD LVCMOS33 } [get_ports { jb[2] }]; #IO_L1P_T0_34 Sch=jb_p[2]
#set_property -dict { PACKAGE_PIN T10   IOSTANDARD LVCMOS33 } [get_ports { jb[3] }]; #IO_L1N_T0_34 Sch=jb_n[2]
#set_property -dict { PACKAGE_PIN V16   IOSTANDARD LVCMOS33 } [get_ports { jb[4] }]; #IO_L18P_T2_34 Sch=jb_p[3]
#set_property -dict { PACKAGE_PIN W16   IOSTANDARD LVCMOS33 } [get_ports { jb[5] }]; #IO_L18N_T2_34 Sch=jb_n[3]
#set_property -dict { PACKAGE_PIN V12   IOSTANDARD LVCMOS33 } [get_ports { jb[6] }]; #IO_L4P_T0_34 Sch=jb_p[4]
#set_property -dict { PACKAGE_PIN W13   IOSTANDARD LVCMOS33 } [get_ports { jb[7] }]; #IO_L4N_T0_34 Sch=jb_n[4]

##Audio Out

#set_property -dict { PACKAGE_PIN R18   IOSTANDARD LVCMOS33 } [get_ports { aud_pwm }]; #IO_L20N_T3_34 Sch=aud_pwm
#set_property -dict { PACKAGE_PIN T17   IOSTANDARD LVCMOS33 } [get_ports { aud_sd }]; #IO_L20P_T3_34 Sch=aud_sd

##Mic input

#set_property -dict { PACKAGE_PIN F17   IOSTANDARD LVCMOS33 } [get_ports { m_clk }]; #IO_L6N_T0_VREF_35 Sch=m_clk
#set_property -dict { PACKAGE_PIN G18   IOSTANDARD LVCMOS33 } [get_ports { m_data }]; #IO_L16N_T2_35 Sch=m_data

##ChipKit Single Ended Analog Inputs
##NOTE: The ck_an_p pins can be used as single ended analog inputs with voltages from 0-3.3V (Chipkit Analog pins A0-A5).
##      These signals should only be connected to the XADC core. When using these pins as digital I/O, use pins ck_io[14-19].
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

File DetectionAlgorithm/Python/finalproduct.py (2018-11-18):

from imutils.video import VideoStream
from collections import deque as d
from enum import Enum
import numpy as np
import argparse
import datetime
import imutils
import cv2
import time
import os
import sys
import copy
import math

min_area = 500
videopath = "../TestData/eirik2.mov"

vs = cv2.VideoCapture(videopath)
vs.set(3,320)
vs.set(4,240)

oldBoundingBox = (0, 0, 0, 0)

def compare_bounding_boxes(b1, b2):
    """
    Returns true if b1 is bigger than b2, otherwise false
    """
    (x1, y1, w1, h1) = b1
    (x2, y2, w2, h2) = b2

    c1 = w1 + w1 + h1 + h1
    c2 = w2 + w2 + h2 + h2

    return c1 > c2


def printProbabilityInBinary(prob):
    # print("%1.6f"%(prob*100))
    numbits = 3
    possibleRepresentationOfAllTheBits = math.pow(2, numbits)
    step = 100/possibleRepresentationOfAllTheBits

    for i in range(0, 8):
        if inRange(prob, i * step, (i + 1) * step):
            byteString = '{0:03b}'.format(i)
            print(byteString)

            writeToGPIO(0, byteString[0])
            writeToGPIO(1, byteString[1])
            writeToGPIO(2, byteString[2])

            break

def writeToGPIO(gpio_number, value):
    print(gpio_number, value)
    #gpio_write[gpio_number] = value
    pass

def inRange(number, a, b):
    if number >= a and number < b:
        return True
    else:
        return False


i = 0

oldsize = -1
oldpos = (-1,-1,-1,-1)
x,y,w,h = 0,0,0,0

# initialize the first frame in the video stream
firstFrame = None

# Dictionary containing a circular framebuffer and a circular list containing 1 if the frame at the
# same index showed something incoming or 0 if the frame at the same index didn't show something
# incoming
BUFFERSIZESMALL = 5
BUFFERSIZELONG  = 25
framebuffer = {
        # frameBuffer contains area of rectangles
        'frameBuffer'  : d(maxlen = BUFFERSIZELONG, iterable = [0 for x in range(BUFFERSIZELONG) ]),
        'incomingshort': d(maxlen = BUFFERSIZESMALL,iterable = [0 for x in range(BUFFERSIZESMALL)]),
        'incominglong' : d(maxlen = BUFFERSIZELONG, iterable = [0 for x in range(BUFFERSIZELONG) ])
        }

# loop over the frames of the video
while True:


    frame = vs.read()[1]
    debugframe = copy.deepcopy(frame)

    if frame is None:
        break
    frame = imutils.resize(frame, width=320)

    gray = cv2.cvtColor(frame, cv2.COLOR_BGR2GRAY)
    gray = cv2.GaussianBlur(gray, (9,9), 0)

    if firstFrame is None:
        firstFrame = gray
        continue

    #compute the absolute difference between the current frame and the first frame
    frameDelta = cv2.absdiff(firstFrame, gray)
    thresh = cv2.threshold(frameDelta, 10, 255, cv2.THRESH_BINARY)[1]

    # dilate the thresholded image to fill in holes, then find contours on thresholded image
    dilation_kernel = cv2.getStructuringElement(cv2.MORPH_CROSS, (3,3))
    thresh = cv2.erode(thresh, dilation_kernel, iterations=1)
    thresh = cv2.dilate(thresh, dilation_kernel,iterations=3)

    cnts = cv2.findContours(thresh.copy(), cv2.RETR_EXTERNAL, cv2.CHAIN_APPROX_SIMPLE)
    cnts = cnts[0] if imutils.is_cv2() else cnts[1]

    # store error values to find the best match later
    epsilon = []
    # Use this to keep track of the previous bounding box
    newBoundingBox = (0, 0, 0, 0)
    rectangles = []

    # loop over the contours
    for c in cnts:
        # if the contour is too small, ignore it
        if cv2.contourArea(c) < min_area:
            continue

        (x, y, w, h) = cv2.boundingRect(c)
        cv2.rectangle(debugframe, (x, y), (x + w, y + h), (0, 0, 255), 2)


        newBoundingBox = (x, y, w, h)


    best = (0,0,0,0)

    if len(rectangles) >= 2:
        bestError = 9999
        bestRectangle = None
        for coordinateNew in rectangles:
            # Normalizing, so we compare the center point of the box
            # this ignores size differences (which can cause the
            # interpretation of position to be skewed)
            deltaX = abs((oldpos[0]+oldpos[2]/2) - (coordinateNew[0] + coordinateNew[2]/2))
            deltaY = abs((oldpos[1]+oldpos[3]/2) - (coordinateNew[1] + coordinateNew[3]/2))
            error = deltaX + deltaY

            if error < bestError:
                bestError = error
                x, y, w, h = coordinateNew[0], coordinateNew[1], coordinateNew[2], coordinateNew[3]
                newBoundingBox = (coordinateNew[0], coordinateNew[1], coordinateNew[2], coordinateNew[3])
                best = (x,y,w,h)

        (x,y,w,h) = best
        oldpos = best
        cv2.rectangle(debugframe, (x, y), (x + w, y + h), (0, 255, 0), 2)
    elif len(rectangles) == 1:
        newBoundingBox = (rectangles[0][0], rectangles[0][1], rectangles[0][2], rectangles[0][3])
        x, y, w, h = rectangles[0][0], rectangles[0][1], rectangles[0][2], rectangles[0][3]
        cv2.rectangle(debugframe, (x, y), (x + w, y + h), (0, 255, 0), 2)
        best = (x,y,w,h)
        oldpos = newBoundingBox
    else:
        oldpos = oldpos

    print("=========")
    if compare_bounding_boxes(newBoundingBox, oldBoundingBox):
        framebuffer['incomingshort'].append(1)
        if(sum(framebuffer['incomingshort']) >= 3):
            framebuffer['incominglong'].append(1)
        print("current box bigger")
        framebuffer['frameBuffer'].append(2*newBoundingBox[2] + 2*newBoundingBox[3])
    else:
        framebuffer['incomingshort'].append(0)
        framebuffer['incominglong' ].append(0)
        framebuffer['frameBuffer'  ].append(2*newBoundingBox[2] + 2*newBoundingBox[3])
        print("current box smaller")


    totArea         = 0
    prob            = 0
    positivesamples = 0
    for i in range(BUFFERSIZELONG):
        totArea += framebuffer['frameBuffer'][i]
        if(framebuffer['incominglong'][i] == 1):
            prob += framebuffer['frameBuffer'][i]
            positivesamples += 1


    negativesamples = BUFFERSIZELONG - positivesamples

    print("total: %6d\tpositive: %2d"%(totArea,positivesamples))
    print("incom: %6d\tpnegative: %2d"%(prob,negativesamples))
    if(totArea != 0 and positivesamples > 3 and negativesamples < 20):
        prob /= totArea
    else:
        prob= 0

    # print("%1.6f"%prob)
    printProbabilityInBinary(prob * 100)

    if(sum(framebuffer['incominglong']) > ((2*BUFFERSIZELONG)/3)):
        print("i think we're colliding")
    else:
        print(23*" ")

    print(str(framebuffer['incomingshort']))
    print(str(framebuffer['incominglong']))
    print("=========")
    print(10*"\033[F")

    oldBoundingBox = newBoundingBox

    cv2.imshow('dilated',thresh)
    # cv2.imshow('pls',pls)
    cv2.imshow('delta', frameDelta)
    cv2.imshow('debugframe',debugframe)

    if( cv2.waitKey(1)&0xFF == 27):
        break
    firstFrame = gray

    i += 1

# cleanup the camera and close any open windows
cv2.destroyAllWindows()

print(framebuffer['incomingshort'])
print(str( sum(framebuffer['incomingshort']) )+"/" + str(BUFFERSIZESMALL))


print(vs.get(3))
print(vs.get(4))

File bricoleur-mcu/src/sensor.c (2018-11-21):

#include "em_cmu.h"
#include "em_gpio.h"
#include "em_timer.h"
#include "em_prs.h"
#include "em_usart.h"
#include "bricoleur.h"
#include "sensor.h"

#define SENSOR_USART UART0
#define SENSOR_USART_PORT ULTRA_PORT
#define SENSOR_USART_PIN ULTRA_PULSE

#define NUM_TRIGGERS 2

const Triggers triggers[] = {
	{.port = ULTRA_PORT, .pin = ULTRA_RX0},
	{.port = ULTRA_PORT, .pin = ULTRA_RX2}
	// Add more trigger port-pin pairs for more sensors here
};

volatile unsigned long milliseconds = 0;
float timer0_ticks_per_us;

void TIMER1_IRQHandler(void) {
	TIMER_IntClear(TIMER1, TIMER_IF_OF);
	milliseconds++;
}

unsigned long millis(void) {
	return milliseconds;
}

void delay(unsigned int m) {
	// Busy wait until at least m milliseconds has passed
	unsigned long start = millis();
	while (millis() - start < m) {
		// wait
	}
}

unsigned int ping_ez0(GPIO_Port_TypeDef port, unsigned int pin) {
	/* How to operate LV-MaxSonar EZ0:
	 *   set trigger high
	 *   wait until R is received over UART
	 *   set trigger low
	 *   distance in inches is received as three ASCII digits, most significant digit first
	 *   a carriage return is received
	 *   wait 5 ms
	 **/
	GPIO_PinOutSet(port, pin);

	while (USART_Rx(SENSOR_USART) != 'R') {}

	GPIO_PinOutClear(port, pin);
	unsigned int digit3 = USART_Rx(SENSOR_USART) - '0';
	unsigned int digit2 = USART_Rx(SENSOR_USART) - '0';
	unsigned int digit1 = USART_Rx(SENSOR_USART) - '0';
//	USART_Tx(USART1, digit3 + '0');
//	USART_Tx(USART1, digit2 + '0');
//	USART_Tx(USART1, digit1 + '0');
//	USART_Tx(USART1, ';');
	USART_Rx(SENSOR_USART);  // \r
	unsigned int inch_distance = digit3 * 100 + digit2 * 10 + digit1;
	delay(5);
	return inch_distance;
}

unsigned int getDistance(unsigned int i) {
	return ping_ez0(triggers[i].port, triggers[i].pin);
}

void setupSensor(void) {
	/* Set up timer 1 to be used in delay() */
	CMU_ClockEnable(cmuClock_TIMER1, true);

	// TIMER1 used for time keeping, interrupt on overflow every millisecond
	NVIC_EnableIRQ(TIMER1_IRQn);
	TIMER_Init_TypeDef timer1_init = TIMER_INIT_DEFAULT;
	TIMER_Init(TIMER1, &timer1_init);
	unsigned long timer1_top = CMU_ClockFreqGet(cmuClock_TIMER1) / 1000;
	TIMER_TopSet(TIMER1, timer1_top);
	TIMER_IntEnable(TIMER1, TIMER_IF_OF);


	/* Set up sensor trigger pins and do sensor startup procedure */
	CMU_ClockEnable(cmuClock_GPIO, true);

	// Set trigger pins as output
	for (int i = 0; i < NUM_TRIGGERS; i++) {
		GPIO_PinModeSet(triggers[i].port, triggers[i].pin, gpioModePushPull, 0);
	}

	// Sensors needs 250 ms to start up after power on
	delay(300);

	// Run calibration cycle, i.e. let each sensor do two 49 ms cycles
	for (int i = 0; i < NUM_TRIGGERS; i++) {
		GPIO_PinOutSet(triggers[i].port, triggers[i].pin);
		// Set RX low after second cycle has started so that it doesn't start a third reading
		delay(75);
		GPIO_PinOutClear(triggers[i].port, triggers[i].pin);
		// Wait rest of cycle
		delay(25);
	}


	/* Set up UART for sensor input
	 * Supports input on all GPIO pin, input is routed to UART using PRS
	 * Sensors output inverted serial, so RX has to be inverted
	 **/
	CMU_ClockEnable(cmuClock_HFPER, true);
	CMU_ClockEnable(cmuClock_UART0, true);
	CMU_ClockEnable(cmuClock_GPIO, true);
	CMU_ClockEnable(cmuClock_PRS, true);

	USART_PRS_Channel_t uartPRSchannel = usartPrsRxCh0;
	USART_InitAsync_TypeDef initAsync = USART_INITASYNC_DEFAULT;
	initAsync.baudrate = 9600;
	initAsync.enable = usartEnableRx;
	initAsync.prsRxEnable = true;
	initAsync.prsRxCh = uartPRSchannel;
	USART_InitAsync(SENSOR_USART, &initAsync);

	SENSOR_USART->ROUTE = USART_ROUTE_RXPEN;
	SENSOR_USART->CTRL |= USART_CTRL_RXINV;

	// Enable input with pull-down
	GPIO_PinModeSet(ULTRA_PORT, ULTRA_PULSE, gpioModeInputPull, 0);
	GPIO_ExtIntConfig(ULTRA_PORT, ULTRA_PULSE, ULTRA_PULSE, false, false, false);

	PRS_SourceSignalSet(uartPRSchannel,
						PRS_CH_CTRL_SOURCESEL_GPIOL,
						PRS_CH_CTRL_SIGSEL_GPIOPIN0,  // The X in GPIOPINX has to be the same as ULTRA_PULSE
						prsEdgeOff);
}

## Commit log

2018-09-18 PCB first commit
    [Bricoleur-pcb.kicad_pcb, Bricoleur-pcb.sch]
2018-09-18 Microcontroller power supply candidate
    [Bricoleur-pcb.sch]
2018-09-19 Power supply done, debug interface started
    [Bricoleur-pcb.sch, file5BBE2084.sch]
2018-09-20 Ultrasonic: get 2D position from distances from sensors
2018-09-20 Ultrasonic: Get 3D position of object from distances from sensors
2018-09-21 Ultrasonic: Interpolate line from set of 2D positions
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2018-09-25 Ultrasonic: Add flow from input via position to line
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2018-09-25 Ultrasonic: Check if object will collide with our system
    [main.c]
2018-09-25 Schematics and footprints almost done
    [Bricoleur-pcb.sch, file5BACB072.sch, file5BBE2084.sch]
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2018-09-27 added new set of test images, with static camera. Updated algorithm to improve stability
    [motion_detector.py]
2018-09-27 Convert to circular buffer. Also, flips logic into correct form in isMoving
    [main.c]
2018-09-27 Start of layout work + minor tweaks
    [Bricoleur-pcb.kicad_pcb, Bricoleur-pcb.sch, file5BBE2084.sch]
2018-09-27 Finished camera connection, started on MC. Changed debug protection diodes sharing pattern to match debug connector.
    [Bricoleur-pcb.kicad_pcb, Bricoleur-pcb.sch, file5BBE2084.sch]
2018-09-28 Fix paths to images, show time in ms
    [motion_detector.py]
2018-09-28 Add sensor interfacing
    Code for the HC-SR04 ultrasonic sensor is included.
2018-09-28 Ultrasonic: Fix and simplify circular buffer
    [main.c]
2018-09-28 More ESD protection, USART output, more footprints
    [Bricoleur-pcb.kicad_pcb, Bricoleur-pcb.sch, ESD-BAT54S.sch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]
2018-09-28 PCB…
    [Bricoleur-pcb.kicad_pcb, Bricoleur-pcb.sch, ESD-BAT54S.sch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]
2018-09-30 Narrowed down component placement, continued routing
    [Bricoleur-pcb.kicad_pcb, Bricoleur-pcb.sch, ESD-BAT54S.sch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]
2018-09-30 Power and clock networks ready (probably).
    [Bricoleur-pcb.kicad_pcb, Bricoleur-pcb.sch, ESD-BAT54S.sch]
2018-09-30 Routing sonars and AUX-UART
    [Bricoleur-pcb.kicad_pcb]
2018-09-30 Moar routing
    [Bricoleur-pcb.kicad_pcb, Bricoleur-pcb.sch, ESD-BAT54S.sch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]
2018-09-30 USB and some other connections, will probably require polish
    [Bricoleur-pcb.kicad_pcb]
2018-10-01 Some routing tweaks
    [Bricoleur-pcb.kicad_pcb]
2018-10-01 Layout finished.
    [Bricoleur-pcb.kicad_pcb, Bricoleur-pcb.sch]
2018-10-03 Ultrasonic: Minor fixes
    struct + typedef -> typedef struct
    int -> unsigned int
    Import needed libraries
    [main.c, sensor.c]
2018-10-03 Header rotated - ethernet connector is too big.
    [Bricoleur-pcb.kicad_pcb]
2018-10-03 Pcb finished???
    [Bricoleur-pcb-B.Cu.gbr, Bricoleur-pcb-B.Mask.gbr, Bricoleur-pcb-B.Paste.gbr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]
2018-10-03 Ultrasonic: Get real input from one sensor to analysis system
2018-10-03 Small fix.
    [Bricoleur-pcb-B.Cu.gbr, Bricoleur-pcb-B.Mask.gbr, Bricoleur-pcb-B.Paste.gbr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]
2018-10-03 Big fookup.
    [Bricoleur-pcb-B.Cu.gbr, Bricoleur-pcb-B.Mask.gbr, Bricoleur-pcb-B.Paste.gbr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]
2018-10-03 Moar fixes.
    [Bricoleur-pcb-B.Cu.gbr, Bricoleur-pcb-B.Mask.gbr, Bricoleur-pcb-B.Paste.gbr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]
2018-10-03 Ultrasonic: Added header files
    Added header files for main and sensor.
    Put in prototypes and structs, but not #defines
2018-10-03 Ultrasonic: Add list of pairs of trigger ports and pins
    getInput() calls getDistance() with an index i argument.
    getDistance gets the distance for sensor i with trigger port and pin i.
2018-10-08 Add basic USART functionality
    Sends distances over UART.
    Also writes sensor 0 and 1 readings to LCD.
2018-10-09 Ultrasonic: Add support for n sensors
    In 2D, handle input from n sensors.
    Always use all sensors, and calculate average position.
2018-10-10 Ultrasonic: Handle if object is not detected by sensor
    If the object is not detected by one of the sensors in a sensor pair, do not use the result from this sensor pair.
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2018-10-15 Ultrasonic: Get correct position and improve output
    Fix a bug which caused the position to be incremented for each iteration instead of being reset.
    Write a lot more output to miniterm, and make it easier to add more.
    Increase baud rate for faster output.
    [main.c]
2018-10-19 Use new sensor setup procedure
    This procedure follows the startup described in
    the sensors' datasheet.
2018-10-24 Read serial ouput from EZ0
    This will use the serial output from the EZ0 instead of
    the pulse output.
    The distance is output in whole inches, so the code
    has been refactored to handle this.
    This removes much of the noise we have seen in the distance
    readings, as the noise were introduced when we were reading the pulses.
    [main.c, sensor.c]
2018-10-26 Ultrasonic: Better handling of real data
    Manual merge from Ultrasonic testdata.
    Flush buffer when detecting wall.
    Detect if an object is not the wall.
2018-10-26 Ultrasonic: Replace buildstring() with strcat()
    [main.c]
2018-10-26 Order functions by when they are called
    Because I was tired of remembering/guessing where a function was.
2018-10-26 Use memset() to reset totalString
    Don't have to use totalStringLength to constantly keep track of how many characters are in the string right now.
    [main.c]
2018-10-26 Ultrasonic: Remove 3D
    3D was not yet used, and I don't think we will use it. Check the git history if you need to add it later.
    Remove 3D function.
    Remove 2D part of 2D functions to simplify.
2018-10-26 Ultrasonic: Remove unused lines
    Remove output code (for LCD display or miniterm) which had not been used in a while, and which was unlikely to be used again.
2018-10-26 Ultrasonic: Replace buildString() by strcat()
    [main.c]
2018-10-29 Use separate U(S)ART for debug and sensor input
2018-10-29 Ultrasonic: Bugfix: Don't overwrite output string
    [main.c]
2018-10-31 clock signal was gone. Now it is back. Hallelujah 🥳
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2018-11-02 small fix to some test 🕋
2018-11-02 WE DID IT BOYS GAUSSIAN BLUR IS A GO 🎉🎉🎉
2018-11-02 Dilation got some fixes 🤠🤠
2018-11-04 PCB specific .h file and further work on mcu mvp
2018-11-05 After some testing in vivado, it seems the gaussian blur now is in sync with both greyscale and the DMA
2018-11-07 Remove LCD code
    Prepare for moving to PCB
2018-11-07 Ultrasonic_to_mcu: Create helper file ultrasonic.c
    main() in main.c can willCollideUltrasonic() in ultrasonic.c
    ultrasonic.c will handle the rest
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2018-11-09 fixed colors on the rectangles, re-added framebuffer for less spasmic results
    [motion_detector.py]
2018-11-09 slight tweak to some filter values, reformat old -> oldsize for clarity
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2018-11-14 mcu: Get a conclusion of the chance of collision from ultrasonic
    Ultrasonic will give a conclusion of the chance of collision as a value between 0 and 1.
    The mcu will then map this local conclusion to a global conclusion which can be used by the imponator.
    [main.c]
2018-11-14 mcu: Smoothen the conclusion from ultrasonic by taking the average of the last conclusions
    Perhaps TODO: Weight the newest conclusions higher.
2018-11-14 Fix USART setup
    Use correct location for USART-AUX and configure it as UART.
    Configure correct USART for USART-FPGA.
    [bricoleur.h, main.c]
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2018-11-15 added a small feature to further reduce noise. Also redone some formatting
    [motion_detector.py]
2018-11-16 Cleanup, labeling, schematic size reduction
    [Bricoleur-pcb.sch, ESD-BAT54S.sch, USART.sch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]
2018-11-17 added printing in binary so we can send it to the mcu
2018-11-17 adding a jupyter notebook that reads from a video file and blinks the led on the pynq of how certain we are that a object will collide
    [finalproduct.py]
2018-11-17 Disable sleep-waiting for data
    Use busy wait for incoming sensor data.
    The sleep approach might have caused some problems, so removing
    it to have one less thing that can go wrong.
    [sensor.c]
2018-11-18 Set up PYNQ communication
    Use three wires for parallel communication instead of UART,
    as UART on the PYNQ was considered to much work.
2018-11-18 Remove unused buffers
    We won't send data to the PYNQ and we will only send single bytes
    on AUX.
    [main.c]
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2018-11-19 mcu: Fix map function
    [main.c]
2018-11-19 Ultrasonic: Weight older conclusions exponentially less
    Instead of taking the average of a buffer of the newest conclusions, we weight newer conclusions more.
    This will hopefully lead to faster update of the conclusion, while still keeping some stability.
    [main.c]
2018-11-19 Ultrasonic: Fix division-by-zero bug when object is not moving or moving slowly
2018-11-19 Ultrasonic: Fix a bug for 1-element buffers
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2018-11-19 Ultrasonic: Fix logic bug
    If isMovingPosition is false, we should not flush the buffer.
    isMovingPositions will return false when buffer.length == 0, and this will lead to the buffer never getting longer than 1.
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2018-11-20 Ultrasonic: Fix output
    Use max value until we see the wall
    Fix a bug where we would get nan
    Combine conclusions from camera and ultrasonic.
    [main.c, sensor.c]

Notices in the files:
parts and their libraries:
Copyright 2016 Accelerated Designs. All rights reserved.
